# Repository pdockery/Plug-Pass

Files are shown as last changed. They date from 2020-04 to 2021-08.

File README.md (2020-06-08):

# Plug-Pass

Clatskanie People's Utility District (PUD) is a public, not-for-profit electric utility, governed by a locally-elected Board of Directors serving the Oregon communities and surrounding areas of Rainier, Westport, and Clatskanie.  The vast majority of our customers commute for work, and Clatskanie PUD designed its electric vehicle to minimize cost and maximize value for its commuting customers.  

Plug-Pass is a subscription-based, electric-vehicle public charging program developed to provide commuters easy access to low-cost charging service at their workplaces.  The first deployment of the Plug-Pass program was at a location where access to the parking spots was easily monitored, and the initial offering only used timers to control electricity.  In considering ways to expand the program to locations that aren't easily monitored, staff is developing low-cost control mechanisms to enable subscribers to initiate charging while preventing unauthorized parties from easily accessing the service.

This program is designed to be open-source in the hope that by sharing the program design broadly we may be able to expand the number of utilities employing similar techniques, and thereby lower the implementation costs for offering the program to more locations in our service territory.

Included in this repository is open-source information that has been used in our pilot program:
* Form of Electric Vehicle Public Charging Rate Design<br>
* Summary of Clatskanie PUD's Electric Vehicle Public Charging Program Design<br>
* Worksheet for calculating public charging rates (pending)<br>
* Form of Plug-Pass subscription agreement (pending)

Under development in this repository are open-source projects to be deployed and tested
* Software for arduino nano based plug-pass outlet control platform
* Control board design and configuration 
* Component list for Plug-Pass outlet

<b>For more information about Clatskanie PUD's EV charging program visit:<b>
https://clatskaniepud.com/ev

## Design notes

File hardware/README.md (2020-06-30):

# Hardware

Contains the design files for the components for the switch including 
* KiCAD files for PCB
* FreeCAD files for 3D printable housing
* Bill of materials to assemble the switch

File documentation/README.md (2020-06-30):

# Documentation

This folder includes documentation used in our pilot program including:
* Summary of Clatskanie PUD's Electric Vehicle Public Charging Program Design
* Summary of Clatskanie PUD's Electric Vehicle Public Charging Rate Design
* Plug-Pass promo video
* Form of Electric Vehicle Public Charging Rate Design
* Worksheet for calculating public charging rates (pending)
* Form of Plug-Pass subscription agreement (pending)

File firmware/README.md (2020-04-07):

# Firmware

This is the directory for arduino nano firmware development.

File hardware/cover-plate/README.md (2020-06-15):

# Cover Plate
A 3D printable cover plate for plug-pass control board

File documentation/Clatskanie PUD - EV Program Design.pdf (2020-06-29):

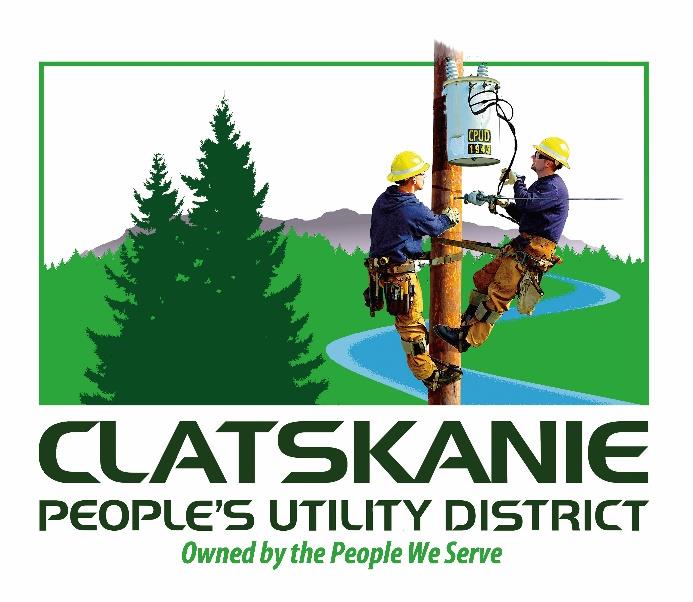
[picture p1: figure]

# Electric Vehicle Public Charging Program Overview

Paul Dockery, Power Manager June 30, 2020

# Clatskanie People’s Utility District

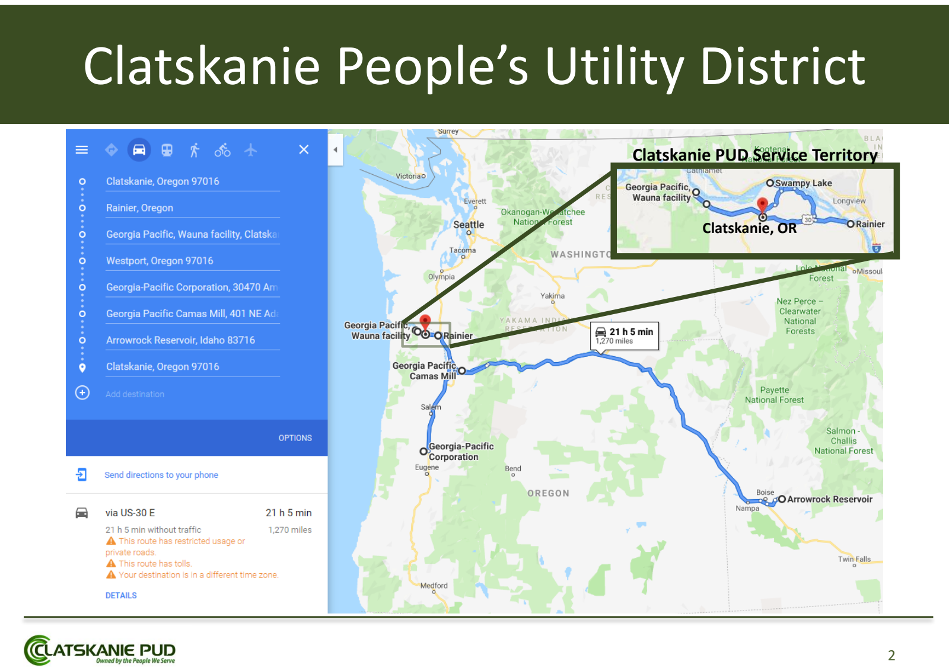
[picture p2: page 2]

Clatskanie PUD Service Territory

Clatskanie, OR

# Program Principles

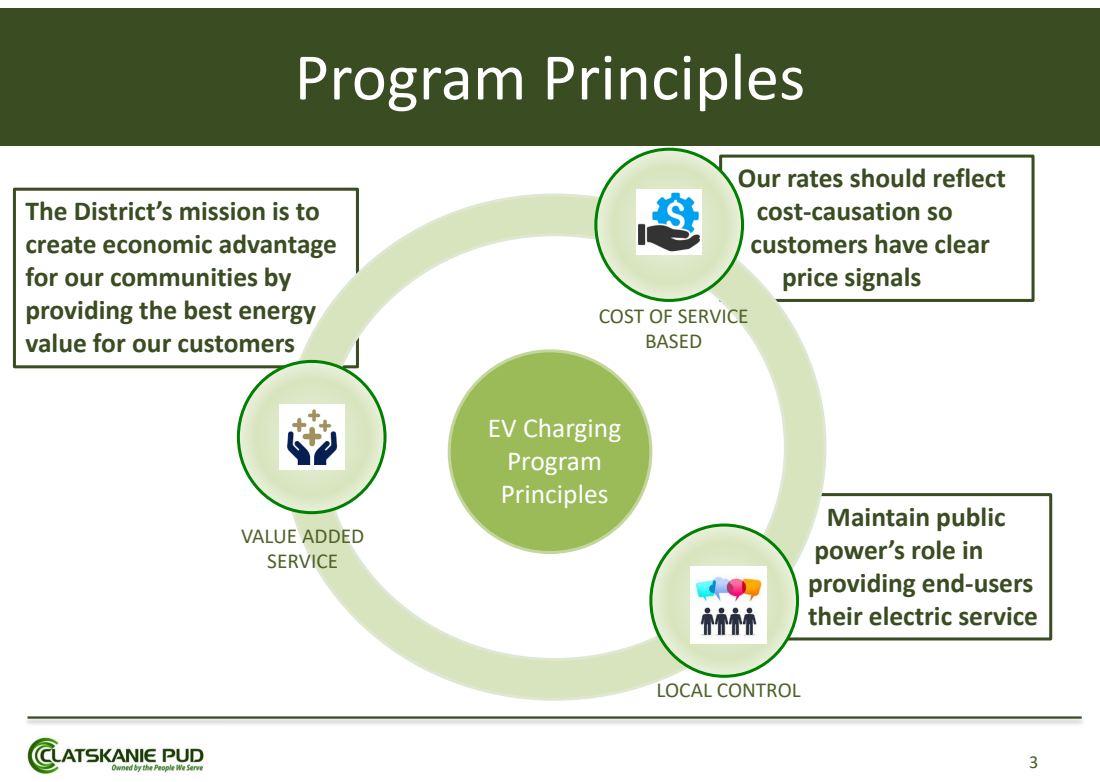
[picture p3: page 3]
EV Charging Program Principles; VALUE ADDED SERVICE; LOCAL CONTROL

Our rates should reflect
cost-causation so
customers have clear
price signals

The District’s mission is to
create economic advantage
for our communities by
providing the best energy
value for our customers

COST OF SERVICE
BASED

Maintain public
power’s role in
providing end-users
their electric service

# “Theory of the Case” for a rural utility EV Charging program

## Our (Clatskanie People’s Utility District) underlying hypotheses:

1. The most prevalent use-case for electric vehicle (“EV”) adoption in the communities we (the “District”) serve will be by commuters
✓ Commuters: Most of our customers (70%) commute for work
x Not fleets: School buses are the only large scale “public transportation” system, and the only meaningful fleet
x Not travelers: Our service territory isn’t a hub for long-haul trucking or a major thoroughfare for travelers
x Not errands: We don’t have many shopping destinations in our service territory that would lend themselves to EV motorists using public chargers during errands

### 2. In-home will be the primary location for EV charging as range continues to

improve (we don’t want to over-invest in public charging infrastructure)
3. High penetration rates of EVs in our service territory increases the District’s peak demand risk, unless charging is done in a smartTM way
4. The consumer-owned utility business model is well suited for providing low-cost electric service to EVs, including public charging services

*Source: U.S. Census Bureau, OnTheMap Application and LEHD Origin-Destination Employment Statistics

### The market we’re targeting is the ~$4.7 million of annual fuel cost paid by the more than 2,800 motorists who commute to or from our service territory to work

# “Theory of the Case” for a rural utility EV Charging program

$-

$20

$40

$60

$80

$100

$120

$140

$160

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
1,000

<10 miles
one way

10-24 miles
one way

25-50 miles
one way

>50 miles
one way

One way cost per commuter per month

# of commuters*

Commuters Living in District

# of Commuters | Fuel Cost

$-

$20

$40

$60

$80

$100

$120

$140

$160

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
<10 miles
one way

10-24 miles
one way

25-50 miles
one way

>50 miles
one way

One way cost per commuter per month

# of Commuters*

Commuters Working in District

# of Commuters | Fuel Cost

# Business Plan Components

## In-Home Charging

## Treat it like any other appliance - In-home charging should be the most cost-effective way for motorists who live in our service territory to re-charge their vehicle - Our residential rate structure is indifferent to end-use, and greater penetration of EVs improves our financial metrics

## Public Charging

## Reduce barriers to adoption and provide competitive services - Own EV public charging equipment - Set rates for end-users of our (owned) public charging equipment that sends price signals which reflect equipment and system costs

# Public Charging Services

## Unmetered outlet

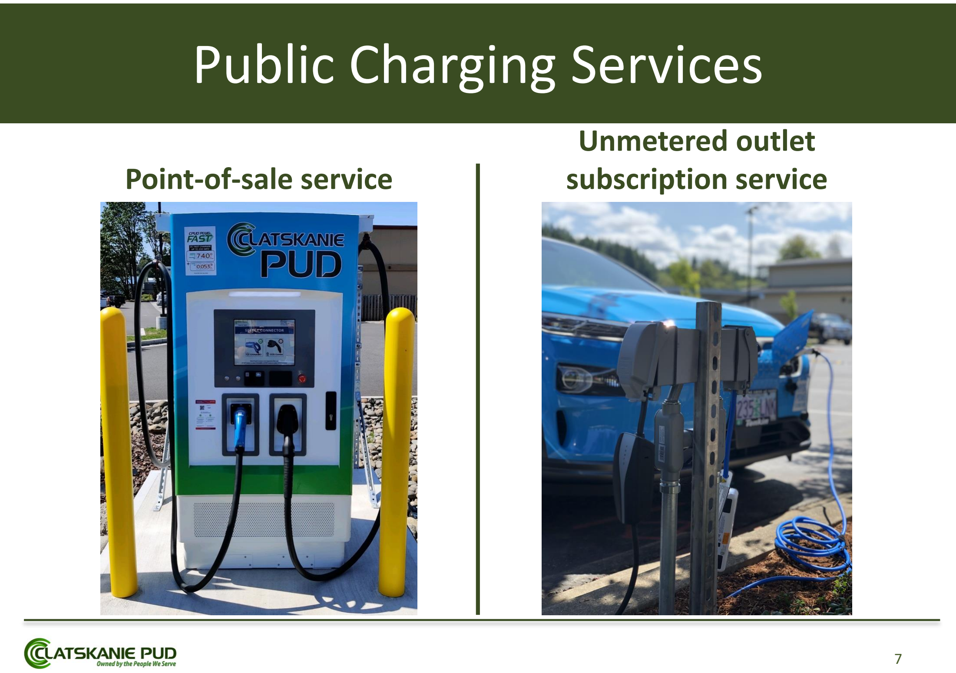
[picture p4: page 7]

## Point-of-sale service

## subscription service

# Unmetered Outlet Subscription Service

### - 120V or 240V outlet installed at commuter parking spots for a fixed monthly fee (we’re branding it “CPUD Plug Pass”)

– The employer provides the parking spot
– The District installs the line extension and outlet (at District expense)
– The District bills the subscribers a fixed monthly fee
– Subscribers provide their own charging cable and pay a fixed monthly fee

- Commuters can top off with their own charging cord using a least-cost-service without having to move their vehicle during the day - Employers don’t have to subsidize EV charging for their employees - The District increases its customer base and energy sales; billing for the subscriptions are processed using our existing software just like any other customer bill, even if they don’t live in the service territory

# Use Cases and Public Charging Services

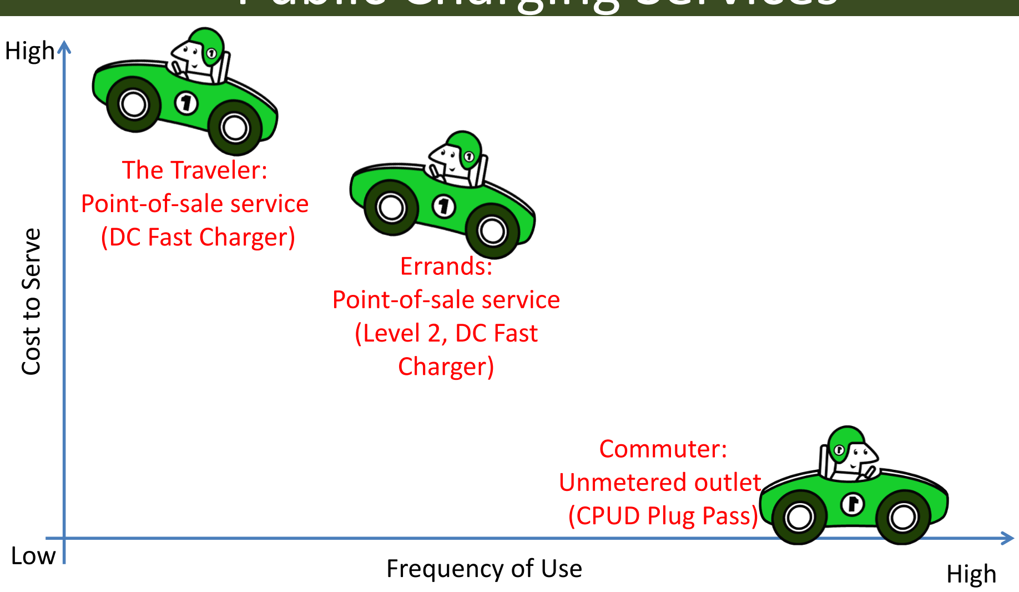
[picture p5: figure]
High; Low; High Cost to Serve; Commuter: Unmetered outlet (CPUD Plug Pass); The Traveler: Point-of-sale service (DC Fast Charger); Errands: Point-of-sale service (Level 2, DC Fast Charger); Frequency of Use

# Public Charging Service Infographic:

# Communicating price signals

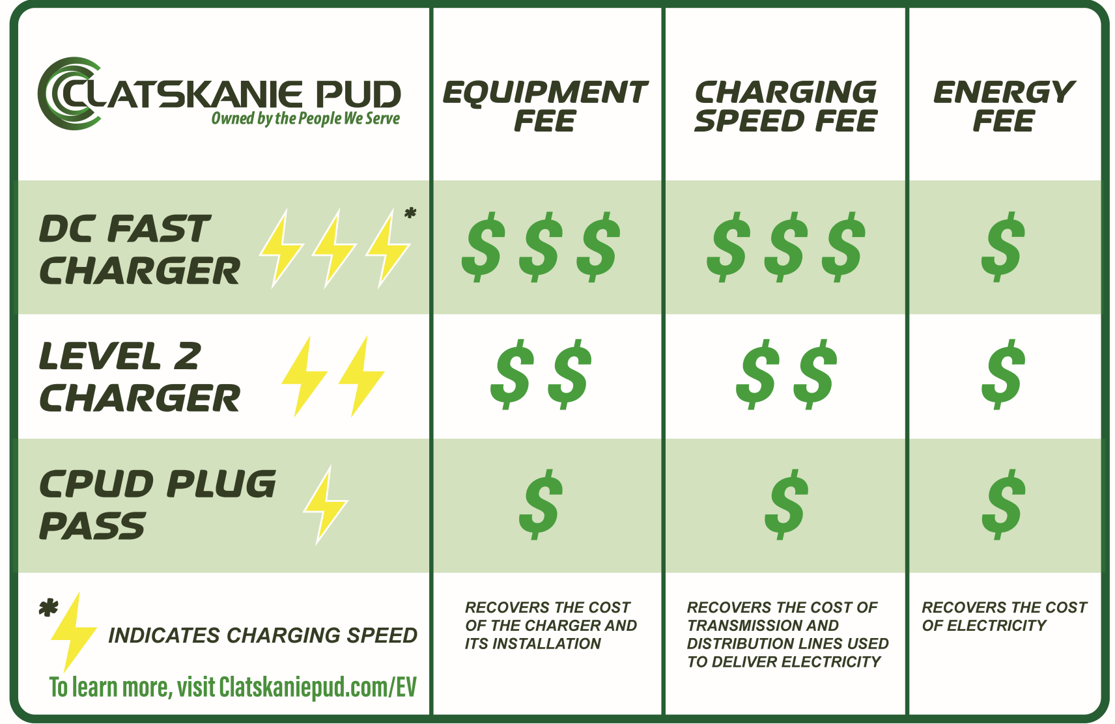
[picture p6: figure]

# Public Charging Rates

# Unmetered Outlet Subscription Service

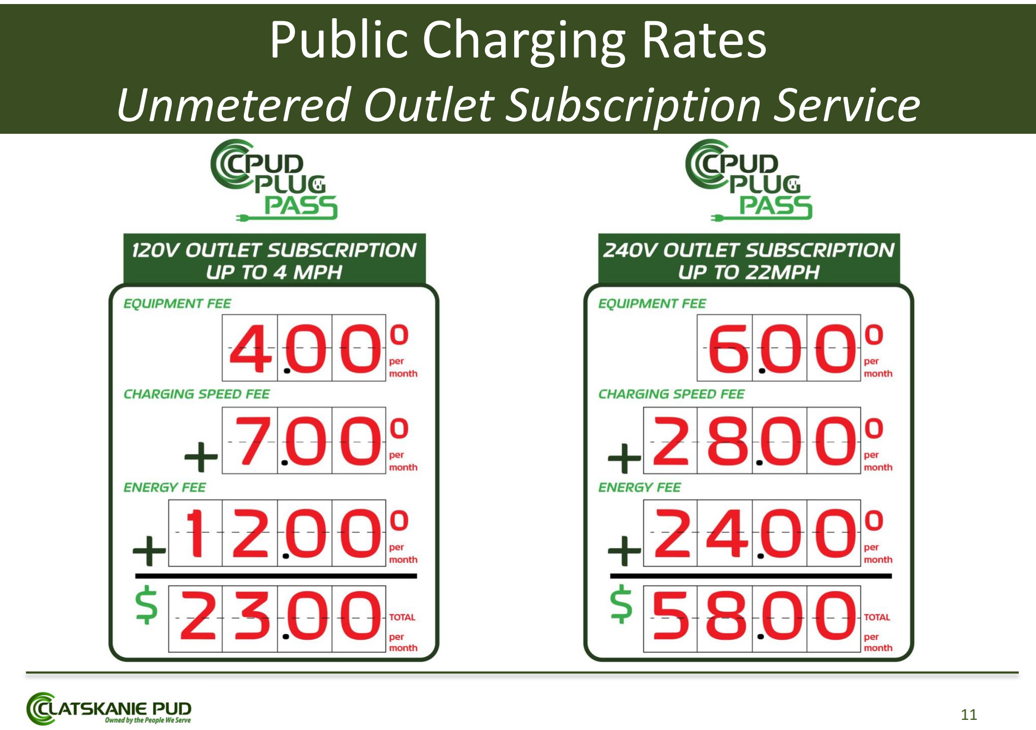
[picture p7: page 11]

*Source: U.S. Census Bureau, OnTheMap Application and LEHD Origin-Destination Employment Statistics

# Value Proposition

$-

$20

$40

$60

$80

$100

$120

$140

$160

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
<10 miles
one way

10-24 miles
one way

25-50 miles
one way

>50 miles
one way

One way cost per commuter per month

# of Commuters*

Commuters Working in District

# of Commuters | Fuel Cost | PUD Subscription/Month

The District increases energy sales and mitigates peak demand risk. Commuters save on fuel cost; the average commuter in our service territory drives 28 miles one-way and would save ~$1,355/year in fuel costs (88% savings on fuel) with an electric vehicle.

$-

$20

$40

$60

$80

$100

$120

$140

$160

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
1,000

<10 miles
one way

10-24 miles
one way

25-50 miles
one way

>50 miles
one way

One way cost per commuter per month

# of commuters*

Commuters Living in District

# of Commuters | Fuel Cost | Electric Cost/Month

# Comparing Commuter Strategies costs incurred by an average commuter

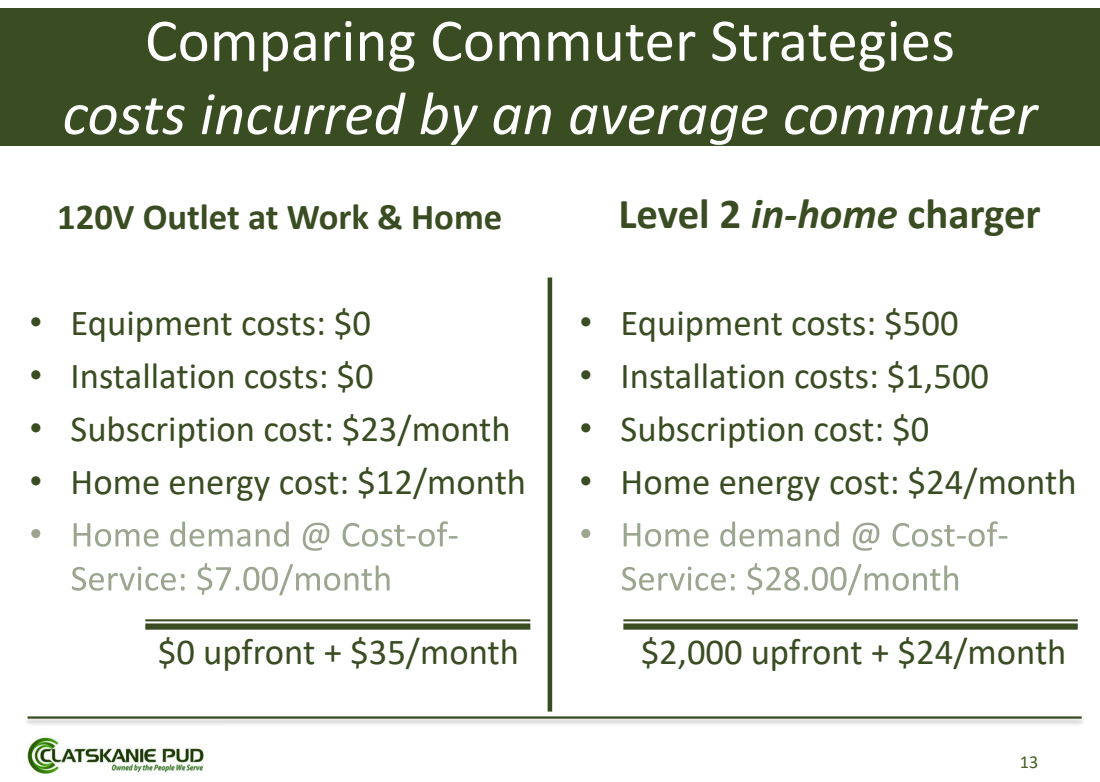
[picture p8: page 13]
$0 upfront + $35/month; $2,000 upfront + $24/month

Level 2 in-home charger

120V Outlet at Work & Home

• Equipment costs: $0
• Installation costs: $0
• Subscription cost: $23/month
• Home energy cost: $12/month

• Equipment costs: $500
• Installation costs: $1,500
• Subscription cost: $0
• Home energy cost: $24/month

# Public Charging Rates

# Point-of-Sale Service

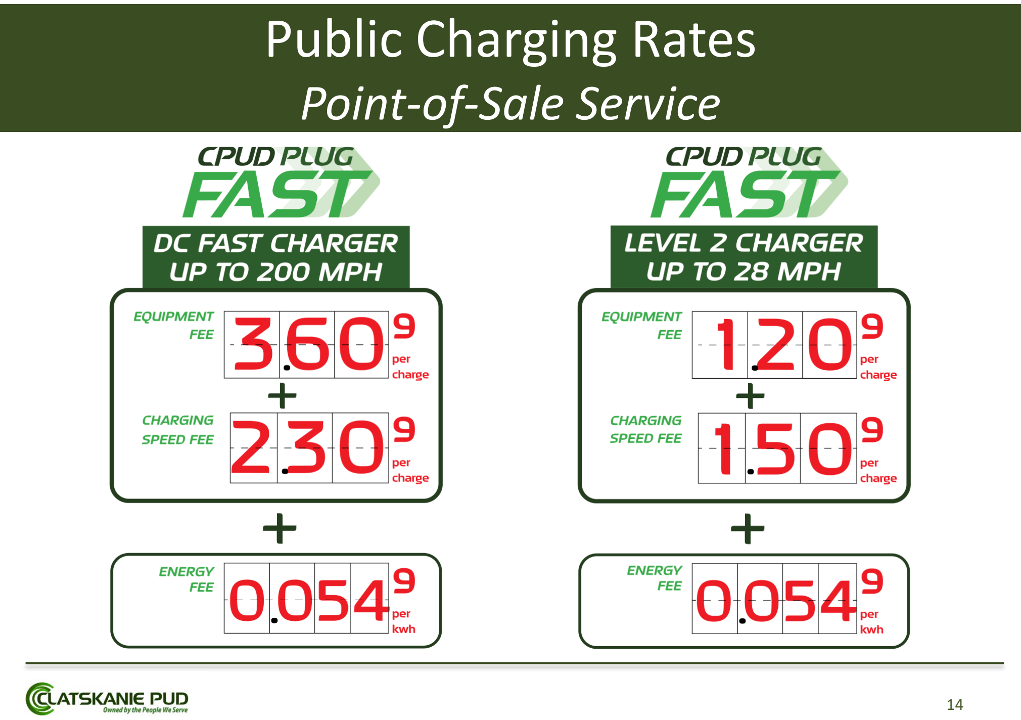
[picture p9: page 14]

# Comparing Workplace EV Public Charging Service Strategies

## Level 2 Charging

## - Costs commuter ~$78/month² - Costs District an estimated $3.3 million¹ to offer program

– 8.1% return on investment

## - Charging is subject to availability - Employees need to coordinate swapping vehicles

## 240V Outlet Charging

## - Costs commuter $58/month - Costs District an estimated $515k¹ to offer program

– 16.7% return on investment

## - Commuter has a reserved parking spot with outlet - Commuter doesn’t need to move car during the day

1
: includes line extensions, DC fast chargers, level 2 chargers, outlets, maintenance, administrative and promotional costs over 25 year program period
: based on same energy consumption as embedded in 240V subscription

# Four arguments for outlets

1. An outlet meets the needs of most commuters
– EVs charge at ~4 miles per hour on a 20 amp, 120V outlet; a commuter plugged into an outlet while parked at home and work for 16 total hours per day would capture ~64 miles worth of energy
– The average daily commute in our (rural) service territory is ~56 miles
2. Level 2 chargers are payment kiosks with an extension cord
– Installing an unmetered outlet instead of a level 2 charger removes the cost of the payment kiosk and extension cord; and simple, low-cost ways to restrict access can be priced into subscriptions
3. Outlets are technology indifferent and less expensive to install
– The low-upfront cost mitigates the risk of slower-than-expect adoption curves
4. Increasing the load-factor of EV charging by spreading charging over more hours at a lower speed makes more efficient use of our distribution system
– PNUCC’s June 2019 report on Electrification¹ highlights that increased workplace charging may have a beneficial impact on evening peaks as well
1. Report titled A Discussion on Electrifying Light Duty Vehicles and Natural Gas Heating in the Northwest https://www.pnucc.org/sites/default/files/PNUCC_NWGA%20Electrification%20Paper_1.pdf

# Closing Thoughts

- Public power utilities can add value through the design of the products and services we offer that others can’t or won’t - Calculating EV public charging fees for end-use-motorists can be simple, the hard part is educating customers on cost-causation - A Charging Speed Fee normalizes charging for peak demand to recover use of transmission and distribution system, and enhances future implementation of Demand Response solutions

- Innovative expansion of low-cost, outlet-based,

## subscription charging increases access to electric vehicles for low-income groups and increases the feasibility of equitable adoption of Zero Emission Vehicles

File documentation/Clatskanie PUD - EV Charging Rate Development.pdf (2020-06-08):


# Electric Vehicle Public Charging Rates

Paul Dockery, Power Manager

# Clatskanie People’s Utility District

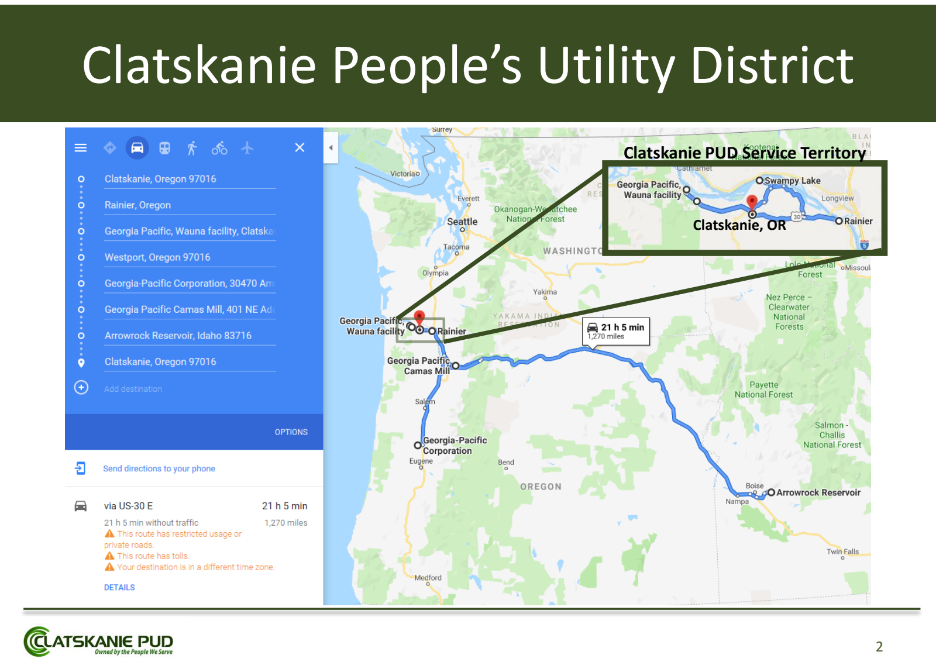
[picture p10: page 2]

Clatskanie PUD Service Territory

Clatskanie, OR

# Program Principles

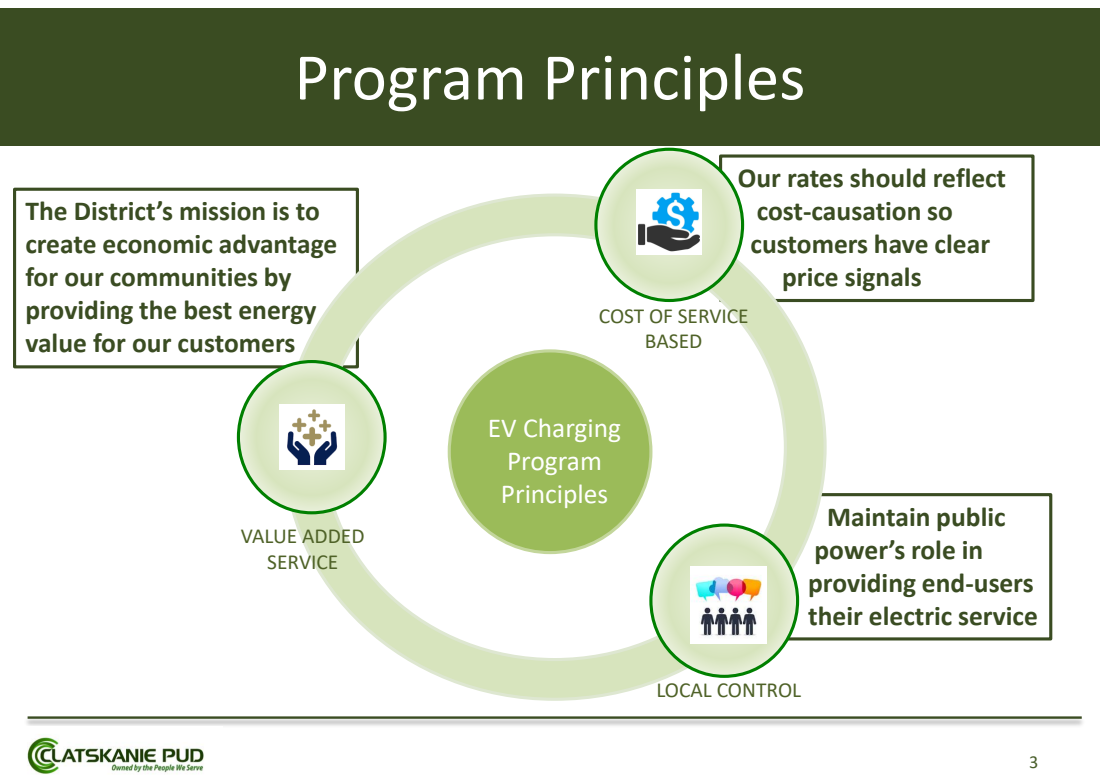
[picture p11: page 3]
EV Charging Program Principles; VALUE ADDED SERVICE; LOCAL CONTROL

Our rates should reflect
cost-causation so
customers have clear
price signals

The District’s mission is to
create economic advantage
for our communities by
providing the best energy
value for our customers

COST OF SERVICE
BASED

Maintain public
power’s role in
providing end-users
their electric service

# “Theory of the Case” for a rural utility EV Charging program

## Our (Clatskanie People’s Utility District) underlying hypotheses:

1. The most prevalent use-case for electric vehicle (“EV”) adoption in the communities we (the “District”) serve will be by commuters
✓ Commuters: Most of our customers (70%) commute for work
x Not fleets: School buses are the only large scale “public transportation” system, and the only meaningful fleet
x Not travelers: Our service territory isn’t a hub for long-haul trucking or a major thoroughfare for travelers
x Not errands: We don’t have many shopping destinations in our service territory that would lend themselves to EV motorists using public chargers during errands

### 2. In-home will be the primary location for EV charging as range continues to

improve (we don’t want to over-invest in public charging infrastructure)
3. High penetration rates of EVs in our service territory increases the District’s peak demand risk, unless charging is done in a smartTM way
4. The consumer-owned utility business model is well suited for providing low-cost electric service to EVs, including public charging services

# Business Plan Components

## In-Home Charging

## Treat it like any other appliance - In-home charging should be the most cost-effective way for motorists who live in our service territory to re-charge their vehicle - Our residential rate structure is indifferent to end-use, and greater penetration of EVs improves our financial metrics

## Public Charging

## Reduce barriers to adoption and provide competitive services - Own EV public charging equipment - Set rates for end-users of our (owned) public charging equipment that sends price signals which reflect equipment and system costs

# Our Program Offerings: EV Public Charging Services

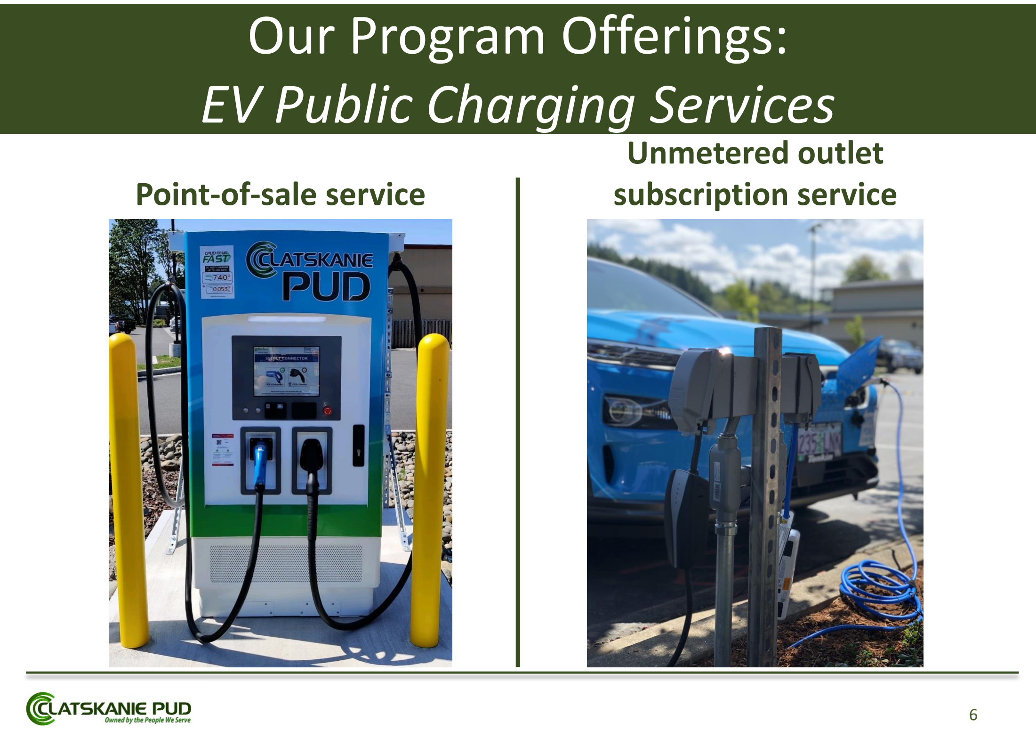
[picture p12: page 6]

## Point-of-sale service

## Unmetered outlet subscription service

# Public Charging Service Infographic:

# Communicating the price of speed


# Public Charging Rates

# Unmetered Outlet Subscription Service

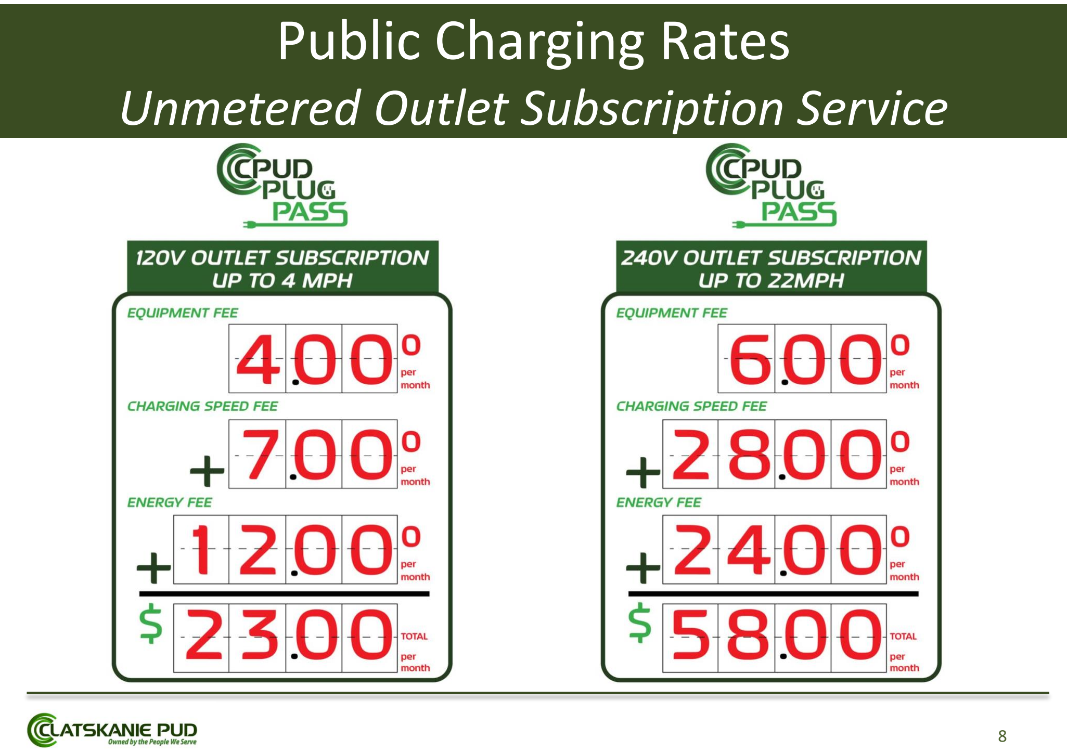
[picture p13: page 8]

# Unmetered Outlet Subscription Service: 120V Outlet Rate Calculation

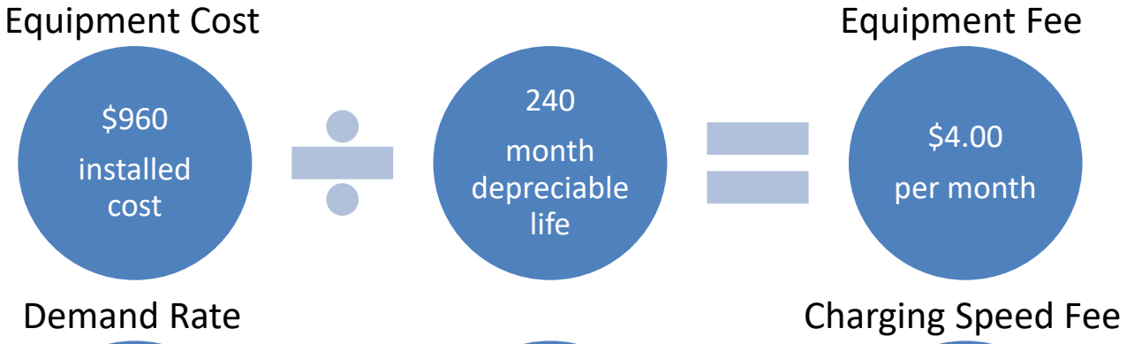
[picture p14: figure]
installed cost; month depreciable life; per month; Equipment Cost; Equipment Fee; Demand Rate; Charging Speed Fee
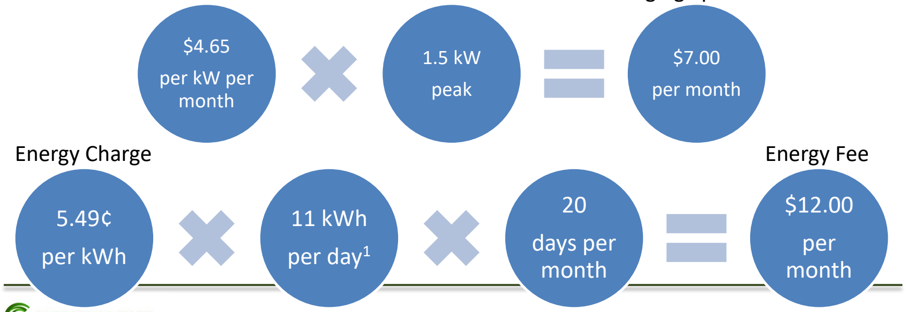
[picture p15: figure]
per kW per month; peak; per month; per kWh; 11 kWh per day¹; days per month; Energy Charge; Energy Fee

: Based on average one-way commute to work for our service territory as published by U.S. Census Bureau, OnTheMap Application and LEHD Origin-Destination Employment Statistics

# Comparing Commuter Strategies costs incurred by an average commuter

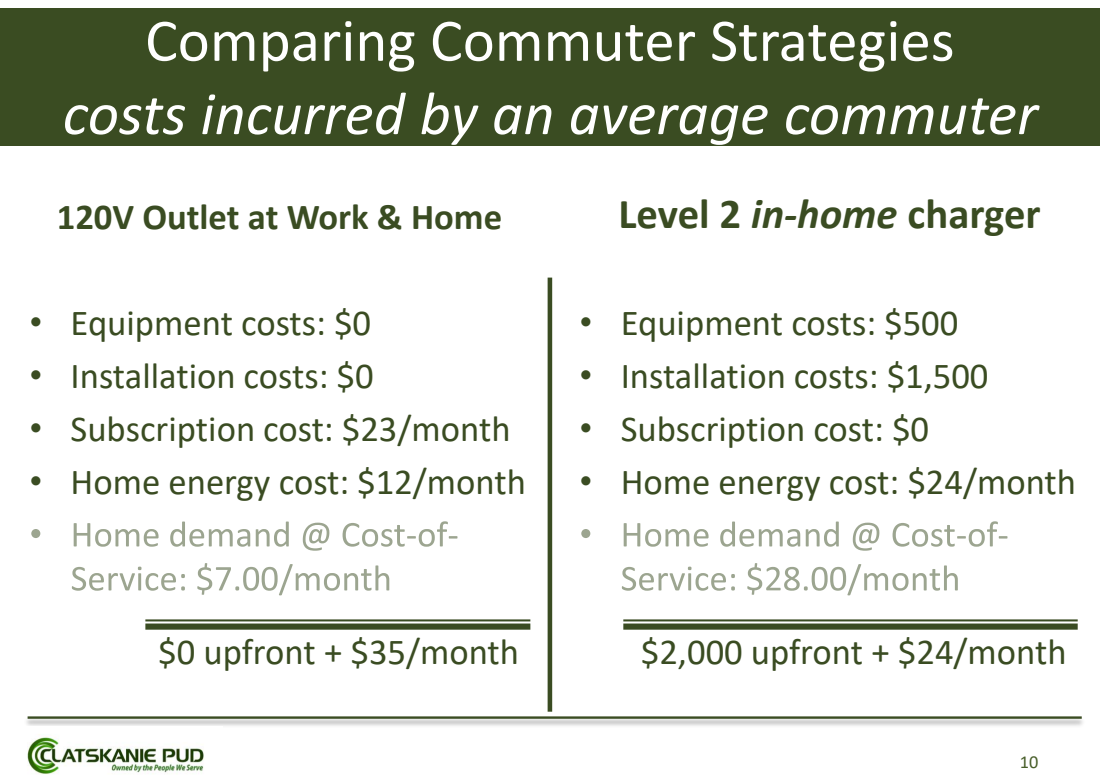
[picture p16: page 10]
$0 upfront + $35/month; $2,000 upfront + $24/month

Level 2 in-home charger

120V Outlet at Work & Home

• Equipment costs: $0
• Installation costs: $0
• Subscription cost: $23/month
• Home energy cost: $12/month

• Equipment costs: $500
• Installation costs: $1,500
• Subscription cost: $0
• Home energy cost: $24/month

# Public Charging Rates

# Point-of-Sale Service

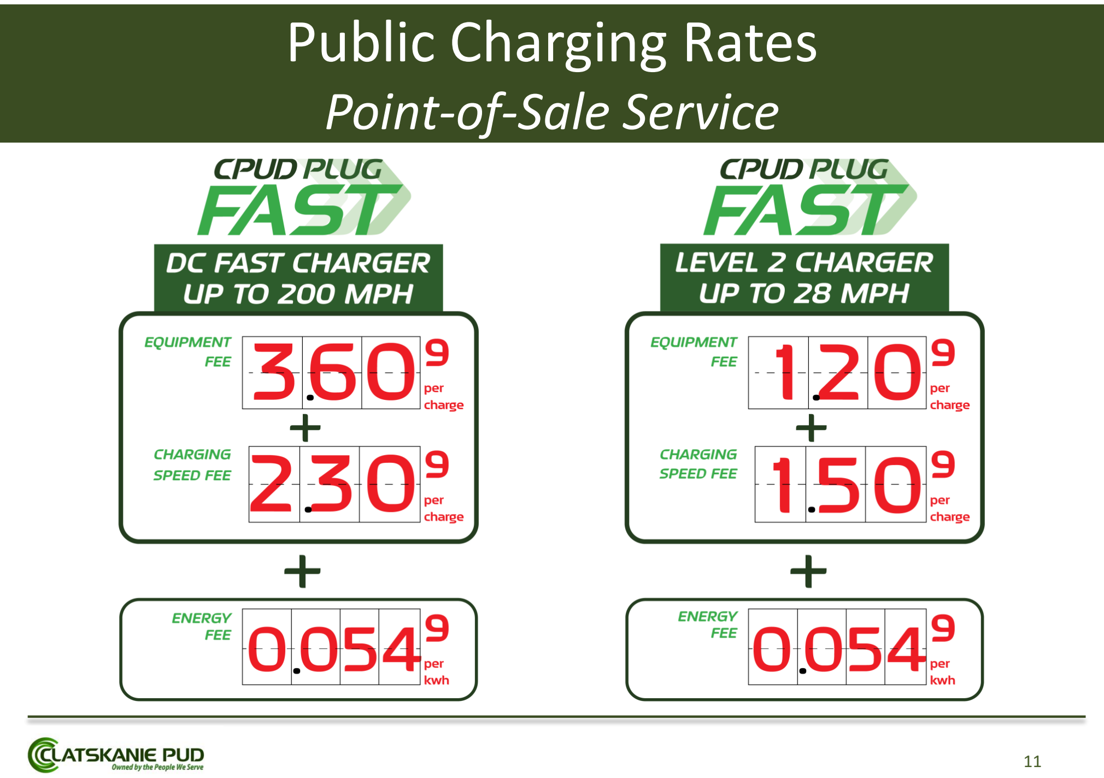
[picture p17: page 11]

# Point-of-Sale Service: DC Fast Charger Rate Calculation

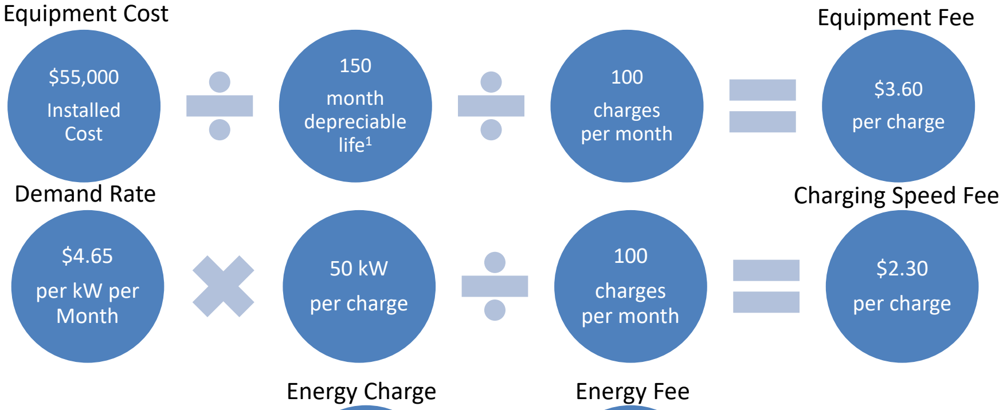
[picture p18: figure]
Installed Cost; month depreciable life¹; charges per month; per charge; Equipment Cost; Equipment Fee; per kW per Month; Demand Rate; Charging Speed Fee; Energy Charge; Energy Fee
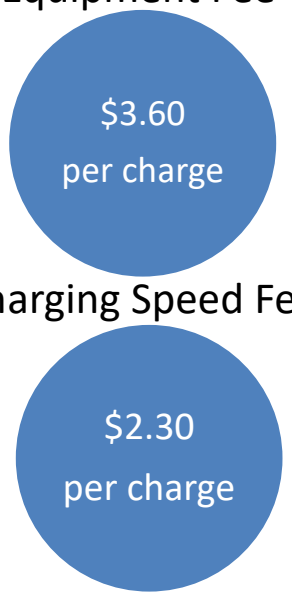
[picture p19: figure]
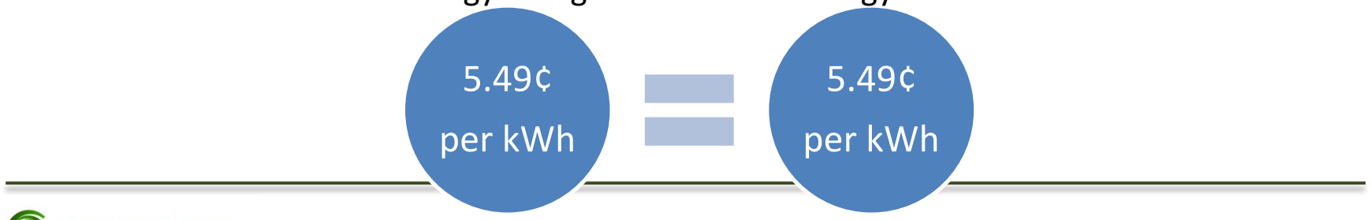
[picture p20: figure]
per kWh

: DC fast charger depreciated over a 10 year period and line extensions depreciated over 20 years

# Point-of-Sale Service: Level 2 Charger Rate Calculation

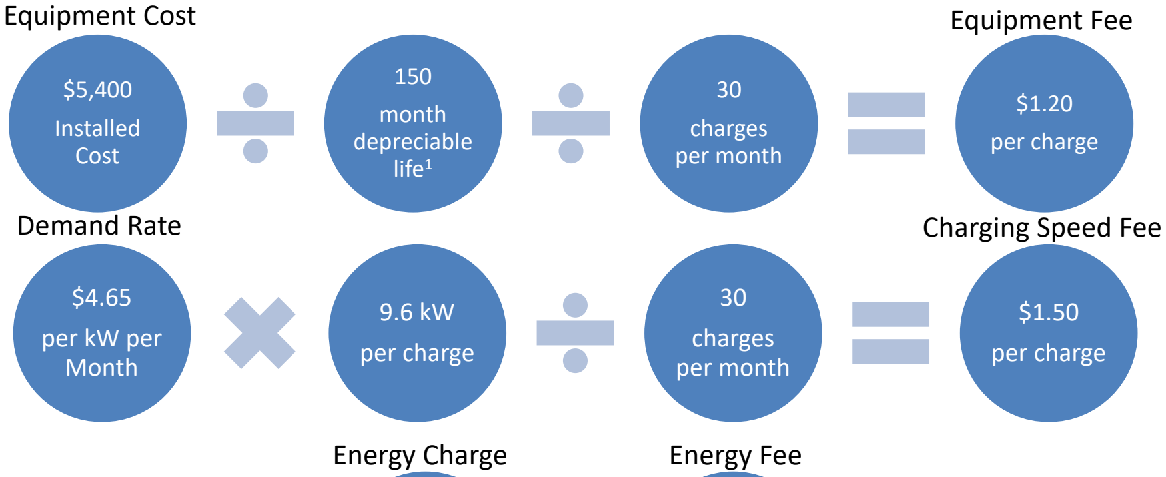
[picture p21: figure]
Installed Cost; month depreciable life¹; charges per month; per charge; Equipment Cost; Equipment Fee; per kW per Month; Demand Rate; Charging Speed Fee; Energy Charge; Energy Fee
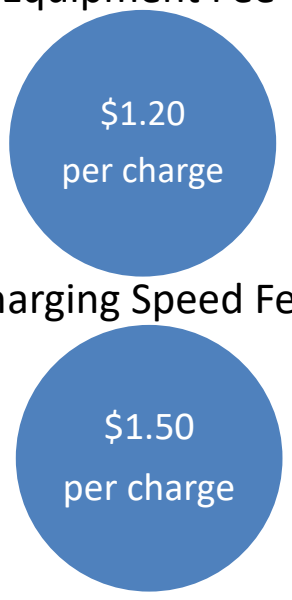
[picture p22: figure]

: Level 2 charger depreciated over a 10 year period and line extensions depreciated over 20 years

# Comparing Workplace EV Public Charging Service Strategies

## Level 2 Charging

## - Costs commuter ~$78/month² - Costs District an estimated $3.3 million¹ to offer program

– 8.1% return on investment

## - Charging is subject to availability - Employees need to coordinate swapping vehicles

## 240V Outlet Charging

## - Costs commuter $58/month - Costs District an estimated $515k¹ to offer program

– 16.7% return on investment

## - Commuter has a reserved parking spot with outlet - Commuter doesn’t need to move car during the day

1
: includes line extensions, DC fast chargers, level 2 chargers, outlets, maintenance, administrative and promotional costs over 25 year program period
: based on same energy consumption as embedded in 240V subscription

# Four arguments for outlets

1. An outlet meets the needs of most commuters
– EVs charge at ~4 miles per hour on a 20 amp, 120V outlet; a commuter plugged into an outlet while parked at home and work for 16 total hours per day would capture ~64 miles worth of energy
– The average daily commute in our (rural) service territory is ~56 miles
2. Level 2 chargers are payment kiosks with an extension cord
– Installing an unmetered outlet instead of a level 2 charger removes the cost of the payment kiosk and extension cord; and simple, low-cost ways to restrict access can be priced into subscriptions
3. Outlets are technology indifferent and less expensive to install
– The low-upfront cost mitigates the risk of slower-than-expect adoption curves
4. Increasing the load-factor of EV charging by spreading charging over more hours at a lower speed makes more efficient use of our distribution system
– PNUCC’s June 2019 report on Electrification¹ highlights that increased workplace charging may have a beneficial impact on evening peaks as well
1. Report titled A Discussion on Electrifying Light Duty Vehicles and Natural Gas Heating in the Northwest https://www.pnucc.org/sites/default/files/PNUCC_NWGA%20Electrification%20Paper_1.pdf

# Competitive Scan: EV Rate Design

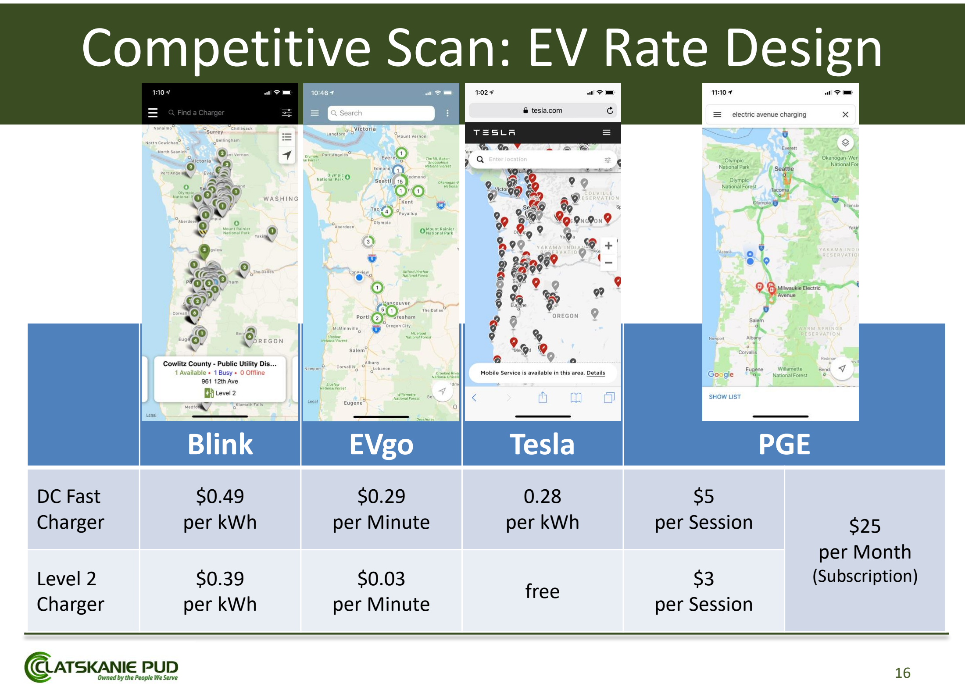
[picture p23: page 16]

| Blink | EVgo | Tesla | PGE
DC Fast Charger | $0.49 per kWh | $0.29 per Minute | 0.28 per kWh | $5 per Session | $25 per Month (Subscription)
Level 2 Charger | $0.39 per kWh | per Minute $0.03 | free | $3 per Session

# Competitive Scan: Public Charging Services

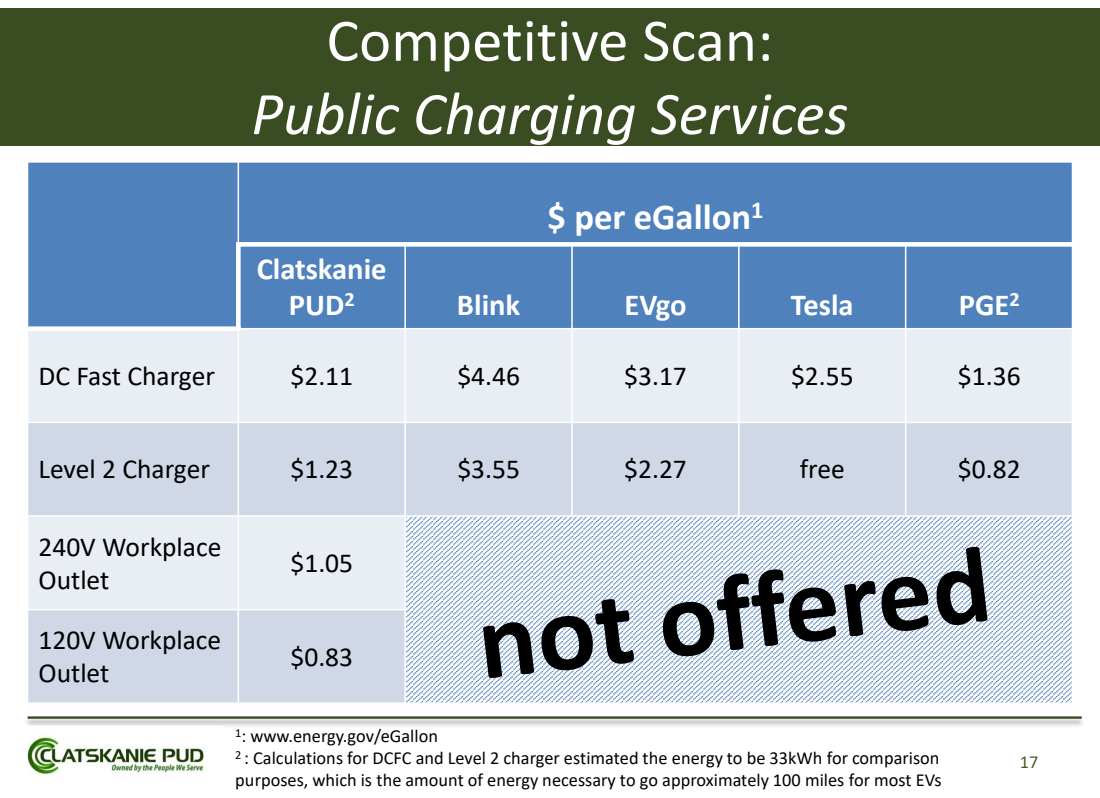
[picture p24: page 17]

$ per eGallon¹

Clatskanie PUD² | Blink | EVgo | Tesla | PGE²

DC Fast Charger | $2.11 | $4.46 | $3.17 | $2.55 | $1.36

Level 2 Charger | $1.23 | $3.55 | $2.27 | free | $0.82

240V Workplace Outlet | $1.05

120V Workplace Outlet | $0.83

: www.energy.gov/eGallon
2 : Calculations for DCFC and Level 2 charger estimated the energy to be 33kWh for comparison
purposes, which is the amount of energy necessary to go approximately 100 miles for most EVs

# Closing Thoughts

- Public power utilities can add value through the design of the products and services we offer that others can’t or won’t - Calculating EV public charging fees for end-use-motorists can be simple, the hard part is educating customers on cost-causation - A Charging Speed Fee may be a good way to normalize the idea of charging for peak demand to recover use of transmission and distribution system - The terms of service for an EV public charging service rate schedule are different than traditional offerings

# Other Resources

# We’re open source!

# All our resources (including this presentation) are available, and updated on GitHub: https://github.com/pdockery/Plug-Pass

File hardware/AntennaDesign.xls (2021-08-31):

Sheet: Antenna Topology I and II
 | Antenna Matching Calculations
Step 1 |  | value | unit | annotation
 | f = | 13560000 | [Hz]
 | omega = | 85199992.77 | [s-1] |  |  |  | calculated
 |  |  |  |  |  |  | to be filled in
 | L0 = | 5.6e-07 | [H]
 | fr0 = | 14400000 | [Hz]
 | C0 calculated = | 2.181359533e-10 | [F]
 | C0 = | 2.2e-10 | [F] | chosen value for C0 | fres = | 14338865.06
 | Rmatch = | 50 | [Ω]
 | Rtr = | 216.6795188
 | Xtr = | -57.8316663
Step 2 | 1st Iteration: Measurement of Antenna parameter La, Rs, Rp,fra
 | Antenna: | linear view | unit | annotation
 | La = | 3.3e-06 | [H]
 | Rs = | 1.2 | [Ω]
 | Rp = | 10900 | [Ω] | at self resonance frequency
 | fra = | 40200000 | [Hz] | self resonance frequency of the antenna
 | Rp (13.56MHz) = | 18767.64067 | [Ω] | Skin effect included
 | Ra = | 5.412 | [Ω]
 | Ca = | 4.749787905e-12 | [F]
 | Qa = | 51.950
 | RQ = | 1.980 | [Ω] | Resistance for a Qa-value of 30
Step 3 | choose an appropriate value for RQ and perform a 2nd antenna measurement for La, Rs, Rp,fra
Step 4 | 2nd Iteration: Measurement of Antenna parameter La, Rs, Rp,fra
 | Antenna: | linear view | unit | annotation
 | La = | 3.3e-06 | [H]
 | Rs = | 1.5 | [Ω]
 | Rp = | 10900 | [Ω] | at self resonance frequency
 | fra = | 40200000 | [Hz] | self resonance frequency of the antenna
 | Rp (13.56MHz) = | 18767.64067 |  | Skin effect included
 | Ra = | 5.712 | [Ω]
 | Ca = | 4.749787905e-12 | [F]
 | Qa = | 49.222
Step 5
 | Antenna: | linear view | unit | annotation
 | Lpa = | 3.3e-06 | [H]
 | Cpa = | 4.749787905e-12 | [F]
 | Rpa = | 13839.23852 | [Ω]
 | Qpa = | 49.222
Step 6 | Calculate Matching Components
 | Matching Circuit: | value | unit | annotation
 | C1 = | 1.402416576e-11 | [F]
 | C2 = | 6.043509275e-11 | [F]
Step 7 | if antenna topology II will be applied please continue with the worksheet "C1 split calculation for AT II"

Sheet: C1 split calculation for AT II
C1 Split Calculations |  |  |  |  | without detuning | with detuning
C1 | 2.12721928e-11 | 21.27 |  |  | 1 | 2
 | Before Split |  | After Split
UEMC without detuning | 5.10 | [V] | 9.50 | [V]
UEMC with detuning | 10.80 | [V] | 6.80 | [V]
UANT without detuning | 24.14 | [V] | 24.14 | [V]
UANT with detuning | 5.00 | [V] | 14.50 | [V]
Average Voltage | 9.469082 | [V]
Percentage seperation of C1: | 22.95 | %
C1S: | 92.70 | [pF]
C2S: | 27.61 | [pF]

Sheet: Antenna Topology III
 | Antenna Matching Calculations
 | The two columns are identical. The left column shows values in scientific units and the right column shows values in a more common format. The columns are independent.
 | The following calculations are only for half of the antenna matching. Rmatch is therefore 35 Ohm instead of 70 Ohm. But the measurement of the antenna itself has to be done for the whole antenna. Equivalent cirquit is for the total antenna!
Step 1 |  | value | unit | easy values | easy unit | annotation | color explanation
 | f = | 13560000 | [Hz] | 13.56 | [MHz] |  |  | to be filled in
 | omega = | 85199992.77 | [s-1] | 85199992.77 | [s-1] |  |  | fixed/calculated values
 | L0 = | 3.3e-07 | [H] | 0.33 | [uH]
 | Rmatch = | 35 | [Ω] | 35 | [Ω]
Step 2 | 1st Iteration: Measurement of Antenna parameter La, Rs, Rp,fra
 | Antenna: | linear view | unit |  |  | annotation
 | La = | 3.2e-06 | [H] | 3.3 | [uH]
 | Rs = | 1.1 | [Ω] | 1.11 | [Ω]
 | Rp = | 80000 | [Ω] | 80 | [kΩ] | at self resonance frequency
 | fra = | 28420000 | [Hz] | 28.4 | [MHz] | self resonance frequency of the antenna
 | Rp (13.56MHz) = | 115816.9647 | [Ω] | 115.776 | [kΩ] | Skin effect included
 | Ra = | 1.742 | [Ω] | 1.793 | [Ω]
 | Ca = | 9.800362453e-12 | [F] | 9.517 | [pF]
 | Qa = | 156.527 |  | 156.828
 | RQ = | 3.673 | [Ω] | 3.790 | [Ω] | Resistance for a Qa-value of 30
Step 3 | choose an appropriate value for RQ and perform a 2nd antenna measurement for La, Rs, Rp,fra
Step 4 | 2nd Iteration: Measurement of Antenna parameter La, Rs, Rp,fra
 | Antenna: | linear view | unit |  |  | annotation
 | La = | 3.3e-06 | [H] | 3.3000 | [uH]
 | Rs = | 7.5 | [Ω] | 7.50 | [Ω]
 | Rp = | 80000 | [Ω] | 80.00 | [kΩ] | at self resonance frequency |  |  | 2514000
 | fra = | 28000000 | [Hz] | 28.0000 | [MHz] | self resonance frequency of the antenna
 | Rp (13.56MHz) = | 114957.989 |  | 114.9580 | [kΩ] | Skin effect included
 | Ra = | 8.188 | [Ω] | 8.1877 | [Ω]
 | Ca = | 9.790621487e-12 | [F] | 9.7906 | [pF]
 | Qa = | 34.340 |  | 34.3395
Step 5
 | Antenna: | linear view | unit |  |  | annotation
 | Lpa = | 3.3e-06 | [H] | 3.3000 | [uH]
 | Cpa = | 9.790621487e-12 | [F] | 9.7906 | [pF]
 | Rpa = | 9654.898073 | [Ω] | 9.6549 | [kΩ]
 | Qpa = | 34.340 |  | 34.340
 | Given Parameters:
 | L0 | 3.3e-07
 | ω | 85199992.77 |  |  | Rmatch | 35
 | Equivalent circuit of the total antenna:
 | Antenna | value | unit |  |  | annotation
 | La = | 3.3e-06 | [H] | 3.300 | [uH]
 | Ca = | 9.790621487e-12 | [F] | 9.791 | [pF]
 | Rp = | 9654.898073 | [Ω] | 9.655 | [kΩ]
 | For calculation of the tuning Capacitors only half of the antenna is needed
 | Antenna | value | unit |  |  | annotation
 | La/2 = | 1.65e-06 | [H] | 1.65 | [uH]
 | Ca*2 = | 1.958124297e-11 | [F] | 19.58 | [pF]
 | Rp/2 = | 4827.449037 | [Ω] | 4.83 | [kΩ]
 | Calculation of Antenna impedance
 | Real_ant = | 6.976664972 |  | 6.977
 | Imag_ant = | 183.387079 |  | 183.387
 | Matching circuit | value | unit |  |  | annotation
 | Calculation of the antenna tuning capacitors
 | C1_1 | 5.805336166e-11 | [F] | 58.05 | [pF]
 | C1_2 | 7.130824243e-11 | [F] | 71.31 | [pF]
 | C0_1 | -3.85222434e-10 | [F] | -385.22 | [pF]
 | C0_2 | 7.126830877e-10 | [F] | 712.68 | [pF]
 | Final tuning values: |  |  |  |  | only 1 solution for C1 and CEMC is possible
 | C1 = | 7.130824243e-11 | [F] | 71.31 | [pF]
 | C0 = | 7.126830877e-10 | [F] | 712.68 | [pF]


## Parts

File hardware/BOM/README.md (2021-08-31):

# Bill of Materials

Datasheets are attached. The datasheet for the ATMEGA328P-AUR was too large to attached. it is available at:

https://www.mouser.com/datasheet/2/268/ATmega48A_PA_88A_PA_168A_PA_328_P_DS_DS40002061B-1900559.pdf

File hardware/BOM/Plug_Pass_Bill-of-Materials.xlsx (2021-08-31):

Item # | Quantity | Reference | Value | Footprint | Description | MPN | Manufacturer | Type
1 | 1 | B1 | CR1220 | CR1220 | CR1220 COIN CELL SM RETAINER | 2894 | Keystone Electronics | SMD
2 | 5 | > C4, C5, C19, C21, C22 | 10µF | 0603-1608X90N | Multilayer Ceramic Capacitors MLCC - SMD/SMT 10UF 25V 10% 0603 | GRM188R61E106KA73D | Murata Electronics | SMD
3 | 7 | > C1-C3, C8, C17, C18, C20 | 0.1µF | 0603-1608X90N | Multilayer Ceramic Capacitors MLCC - SMD/SMT 50V .1uF X7R 0603 10% AEC-Q200 | C0603C104K5RAC3121 | KEMET | SMD
4 | 2 | > C11, C14 | 220pF | 0402-1005X55N | Multilayer Ceramic Capacitors MLCC - SMD/SMT 50V 220pF X7R 0402 10% AEC-Q200 | C0402S221K5RACAUTO | KEMET | SMD
5 | 1 | C23 | 1000pF | 0603-1608X90N | Multilayer Ceramic Capacitors MLCC - SMD/SMT 50V 1000pF X7R AUTO 5mm Flex VW80808 | C0603X102K5RAC3316 | KEMET | SMD
6 | 2 | > C24, C25 | 33pF | 0603-1608X90N | Multilayer Ceramic Capacitors MLCC - SMD/SMT 50V 33pF 0603 X8R 10% AEC-Q200 | C0603C330K5HACAUTO | KEMET | SMD
7 | 2 | > C26, C28 | 1µF | 0402-1005X55N | Multilayer Ceramic Capacitors MLCC - SMD/SMT 0402 25VDC 1uF 10% | GRM155R61E105KA12D | Murata Electronics | SMD
8 | 2 | > C27, C31 | 4,7uF_16V | CAPAE430X550N | Aluminum Electrolytic Capacitors - SMD WCAP-ASNP 4.7uF 16V 20% SMD/SMT | 865250340002 | Wurth Elektronik | SMD
9 | 3 | > C29, C30, C33 | 100nF | 0402-1005X55N | Multilayer Ceramic Capacitors MLCC - SMD/SMT .1UF 50V 5% 0402 | GRM155R61H104JE14D | Murata Electronics | SMD
10 | 1 | C32 | 1uF | 0402-1005X55N | Multilayer Ceramic Capacitors MLCC - SMD/SMT 0402 25VDC 1uF 10% | GRM155R61E105KA12D | Murata Electronics | SMD
11 | 1 | D1 | 0025_SS1P3L-M3_84A | DO220AAL | Schottky Diodes & Rectifiers 30volt 1.0amp | SS1P3L-M3/84A | Vishay Semiconductors | SMD
12 | 1 | F1 | MFFSMF050 | 0603-1608X90N | Resettable Fuses - PPTC 6volts 40amps | MF-FSMF050X-2 | Bourns | SMD
13 | 1 | IC1 | DS3231M | Package_SO:SOIC-16W_7.5x10.3mm_P1.27mm | Real Time Clock +/-5ppm, I C Real-Time Clock | DS3231M+ | Maxim Integrated | SMD
14 | 1 | IC2 | PN532 | HVQFN40-6X6 | IC RFID RDR/TRAN 13.56MZ 40HVQFN | PN5321A3HN/C106,55 | NXP USA Inc. | SMD
15 | 0 | IC3 | NA | NA | NA | NA | NA | NA
16 | 1 | IC4 | FT232RL | digikey-footprints:SSOP-28_W5.30mm | IC USB FS SERIAL UART 28-SSOP | FT232RL-REEL | FTDI, Future Technology Devices International Ltd | SMD
17 | 1 | IC5 | ATMEGA328P-AUR | digikey-footprints:TQFP-32_7x7mm | IC MCU 8BIT 32KB FLASH 32TQFP | ATMEGA328P-AUR | Microchip Technology | SMD
18 | 1 | J1 | USB_B_Micro | MOLEX_1051330001 | USB Connectors MICRO USB B RECPT VERTICAL | 1051330001 | Molex | SMD & through-hole
19 | 1 | J2 | 505568-0271 | 5055680271 | CONN HEADER SMD 2POS 1.25MM | 5055680271 | Molex | SMD
20 | 1 | L1 | Yellow | LEDC1608X80N-AK | Standard LEDs - SMD Yellow Diffused 586nm 8mcd | HSMY-C190 | Broadcom | SMD
21 | 2 | > L3, L4 | 560nH | 0805-R2013X50N | Fixed Inductors 560nH 5% | CW201212-R56J | Bourns | SMD
22 | 2 | > L2, L5 | FERRITE | 0805-R2013X50N | Ferrite Beads 0805 0.12ohm 100MHz 1.6A | BLM21SP102SN1D | Murata Electronics | SMD
23 | 1 | PS1 | IRM-03-5 | Converter_ACDC:Converter_ACDC_MeanWell_IRM-03-xx_SMD | AC/DC CONVERTER 5V 3W | IRM-03-5S | MEAN WELL USA Inc. | SMD
24 | 1 | PWR1 | Green | LEDC1608X80N-AK | Standard LEDs - SMD Green Diffused 572nm 5mcd | HSMG-C190 | Broadcom | SMD
25 | 2 | > R2, R4 | 10k | 0402-1005X55N | Thick Film Resistors - SMD 10K OHM 1% | RC0402FR-0710KL | Yageo | SMD
26 | 1 | R7 | 1.0k | 0402-1005X55N | Thick Film Resistors - SMD 1K ohm 5% 50V General Purpose | RC0402JR-131KL | Yageo | SMD
27 | 1 | R8 | 1.69k | 0402-1005X55N | Thick Film Resistors - SMD 1.69K OHM 1% | RC0402FR-071K69L | Yageo | SMD
28 | 4 | > R9-R12 | 330 | 0402-1005X55N | Thick Film Resistors - SMD 330 OHM 1% | RC0402FR-07330RL | Yageo | SMD
29 | 1 | RLY1 | T9AS1D22-5 | RLY-T9AS1D22-5 | RELAY GEN PURPOSE SPST 30A 5V | T9AS1D22-5 | TE Connectivity Potter & Brumfield Relays | through-hole
30 | 1 | RLY2 | G5V-1-DC5 | Relay_THT_G5V-1 | RELAY GEN PURPOSE SPDT 1A 5VDC | G5V-1-DC5 | Omron Electronics Inc-EMC Div | through-hole
31 | 1 | RP1 | 1k | CAY16 | Resistor Networks & Arrays 1K 5% Convex 4resistors | CAY16-102J4LF | Bourns | SMD
32 | 1 | RX1 | Red | LEDC1608X80N-AK | Standard LEDs - SMD Red Diffused 639nm 17mcd | HSMH-C190 | Broadcom | SMD
33 | 1 | SW1 | RESET | C&K_PTS820_NO_HOLES | Tactile Switches Microminiature SMT Top Actuated | PTS820J25KSMTRLFS | C&K | SMD
34 | 1 | TX1 | Green | LEDC1608X80N-AK | Standard LEDs - SMD Green Diffused 572nm 5mcd | HSMG-C190 | Broadcom | SMD
35 | 1 | Y1 | 27.12MHz | 7M27120MAAJT | Crystals 27.120MHz 30ppm -20 +70C 18pF | 7M-27.120MAAJ-T | TXC Corporation | SMD
36 | 0 | Y2 | NA | NA | NA | NA | NA | NA
37 | 2 | C35, C36 | 22pF | 0603-1608X90N | Multilayer Ceramic Capacitors MLCC - SMD/SMT 22pF 50V NPO 5% | CC0603JRNPO9BN220 | Yageo | SMD | https://www.mouser.com/ProductDetail/Yageo/CC0603JRNPO9BN220?qs=vTakOoo5QyIVMYOUTI%2F4zA%3D%3D
39 | 2 | C6, C15 | 15pF | C_0805_2012Metric | Multilayer Ceramic Capacitors MLCC - SMD/SMT 50V 15pF C0G 0805 5% | CC0805JRNPO9BN150 | Yageo | SMD | https://www.mouser.com/ProductDetail/Yageo/CC0805JRNPO9BN150?qs=vTakOoo5QyIdTjxE3H8vpA%3D%3D
40 | 2 | C10, C13 | 62pF | C_0805_2012Metric | Multilayer Ceramic Capacitors MLCC - SMD/SMT 62pF 50V NPO 5% | CC0805JRNPO9BN620 | Yageo | SMD | https://www.mouser.com/ProductDetail/Yageo/CC0805JRNPO9BN620?qs=57cj7OiSijn%2FWRr%252BD6Xa6w%3D%3D
41 | 1 | D2 | NA | SODFL2512X100N | DIODE GEN PURP 75V 150MA SOD323F | 1N4148WS | ON Semiconductor | SMD | https://www.digikey.com/en/products/detail/on-semiconductor/1N4148WS/1873805
42 | 0 | Q1 | NA | NA | NA | NA | NA | NA | https://www.mouser.com/Semiconductors/Discrete-Semiconductors/Transistors/Bipolar-Transistors-BJT/_/N-ax1sh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
43 | 1 | R13 | 4.7k | 0402-1005X55N | Thick Film Resistors - SMD 4.7 kOhms 62.5 mW 0402 5% | RC0402JR-7D4K7L | Yageo | SMD | https://www.mouser.com/ProductDetail/Yageo/RC0402JR-7D4K7L?qs=HEu%2FF%2FCqxzL%2FxemeTzhmAg%3D%3D
44 | 2 | R1, R6 | 2 | Resistor_SMD:R_0805_2012Metric | Thick Film Resistors - SMD 1/4watts 2ohms 5% | RK73B2ATTD2R0J | KOA Speer | SMD | https://www.mouser.com/ProductDetail/KOA-Speer/RK73B2ATTD2R0J?qs=rx%252BqewZzWUdjzAQpUO86bw%3D%3D
45 | 1 | J3 | 1x8 | PinSocket_1x08_P2.54mm_Vertical_SMD_Pin1Right | CONN HDR 8POS 0.1 TIN SMD | NPTC081KFXC-RC |  | SMD | https://www.digikey.com/en/products/detail/sullins-connector-solutions/NPTC081KFXC-RC/776058

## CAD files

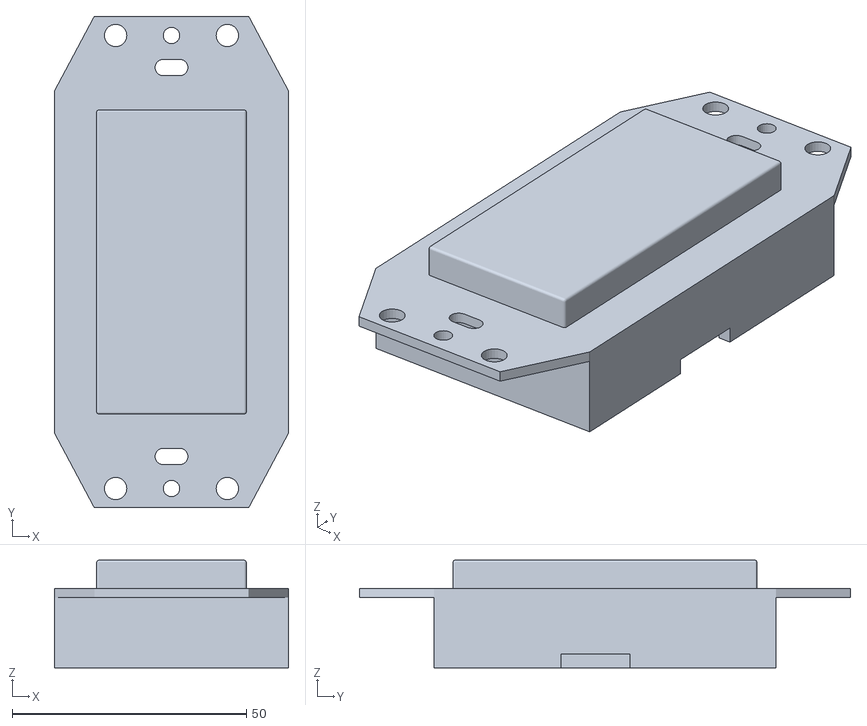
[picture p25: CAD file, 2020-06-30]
hardware/cover-plate/Plug-Pass-cover.stl
50.0 x 105.0 x 23.0

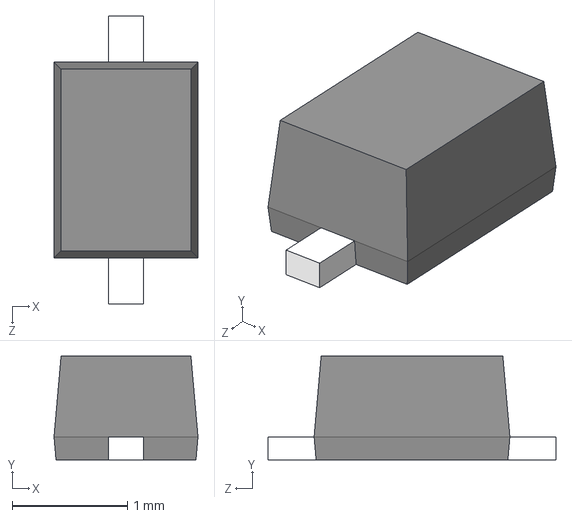
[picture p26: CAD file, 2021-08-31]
hardware/PCB/Update3-2/1N4148WS/1N4148WS.step
1.25 x 0.9 x 2.50 mm

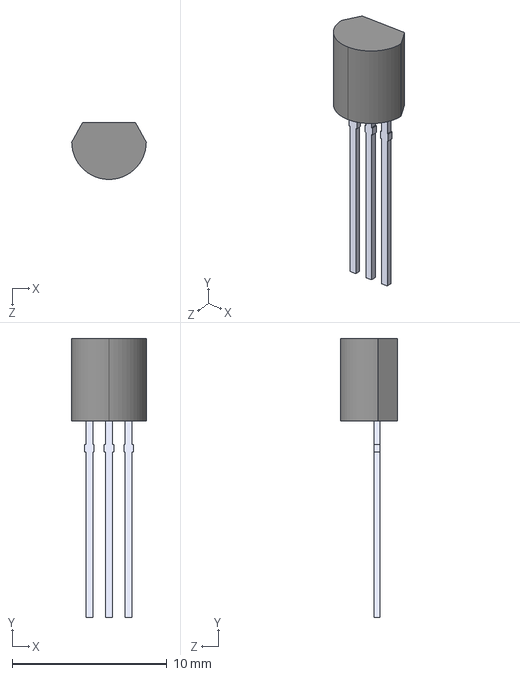
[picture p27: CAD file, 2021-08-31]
hardware/PCB/Update3-2/2N3904/2N3904.step
4.83 x 18.0 x 3.68 mm

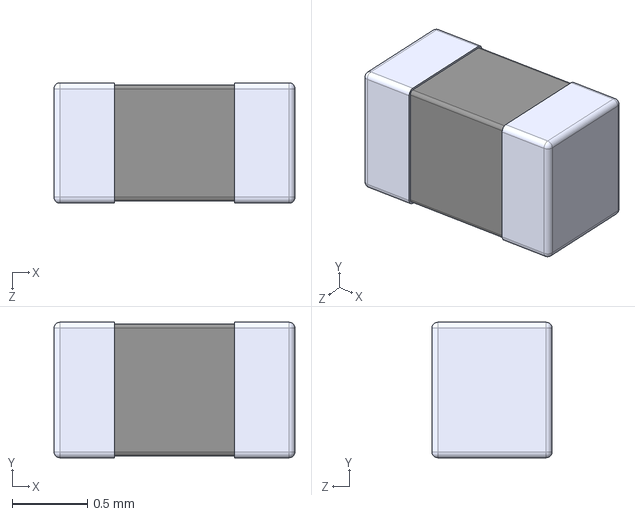
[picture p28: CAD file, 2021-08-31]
hardware/PCB/Update3-2/CC0603JRNPO9BN220/CC0603JRNPO9BN220.step
1.60 x 0.9 x 0.8 mm

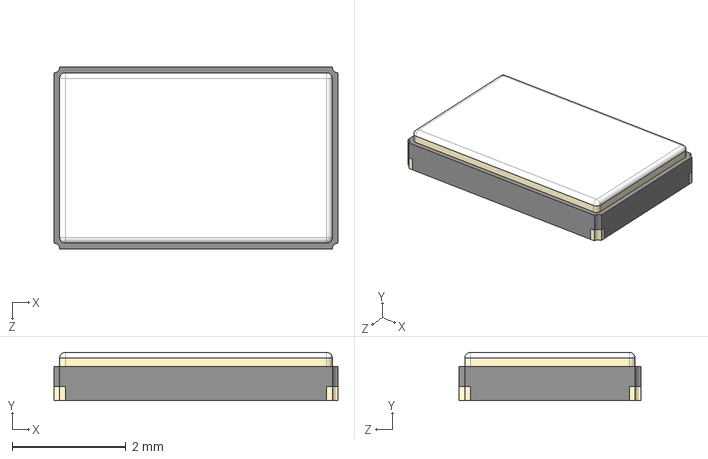
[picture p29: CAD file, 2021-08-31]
hardware/PCB/Update3-2/ECS-160-20-30B-AGL-TR/ECS-160-20-30B-AGL-TR.step
5.00 x 0.85 x 3.20 mm

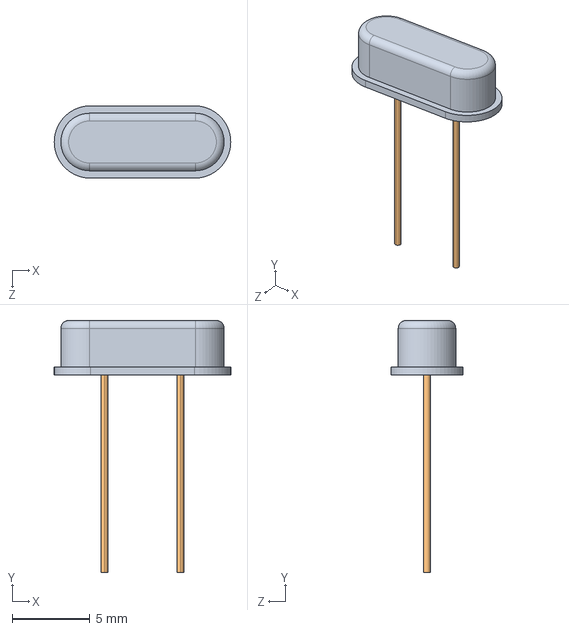
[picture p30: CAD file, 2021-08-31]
hardware/PCB/Update3-2/ECS-51-20-4/ECS-51-20-4.step
11.4 x 16.2 x 4.65 mm

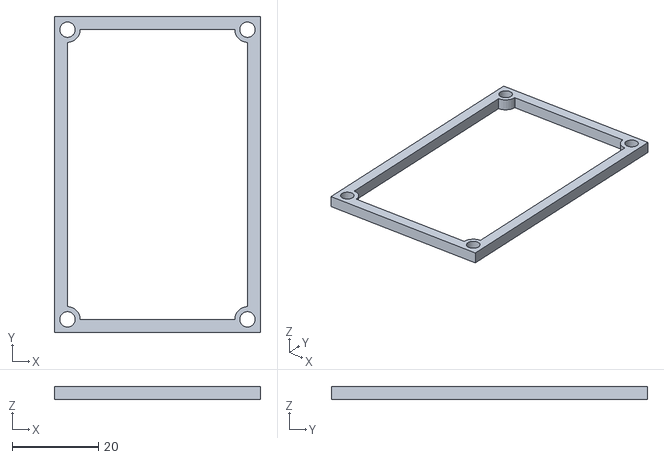
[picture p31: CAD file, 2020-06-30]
hardware/cover-plate/Plug-Pass-AC-Spacer.stl
47.8 x 73.2 x 3.00

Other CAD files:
hardware/cover-plate/Plug-Pass_Switch_Cover_v2-0.FCStd
hardware/cover-plate/Plug-Pass_AC-Spacer_v2-0.FCStd

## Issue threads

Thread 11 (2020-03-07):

Sync time by phone swipe

El1-G, 2020-03-07:
We need to add a function in the loop where if the rtc has lost power (battery failure or replacement) we are able to sync the time via a phone nfc swipe. This will also require a unique authentication key for an administrator level privilege.

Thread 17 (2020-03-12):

Susceptibility to interference on pin 12

pdockery, 2020-03-12:
I think i'm introducing some weakness in the code by reading D12 to determine if it's HIGH or LOW to decide whether to turn on or off.  it susceptible to inadvertent voltage interference on that circuit path.  Instead, i think i should write to a dummy variable whether it's high or low and track that variable with the pin write commands so it mirrors the coded output.

Closed 2020-03-16.

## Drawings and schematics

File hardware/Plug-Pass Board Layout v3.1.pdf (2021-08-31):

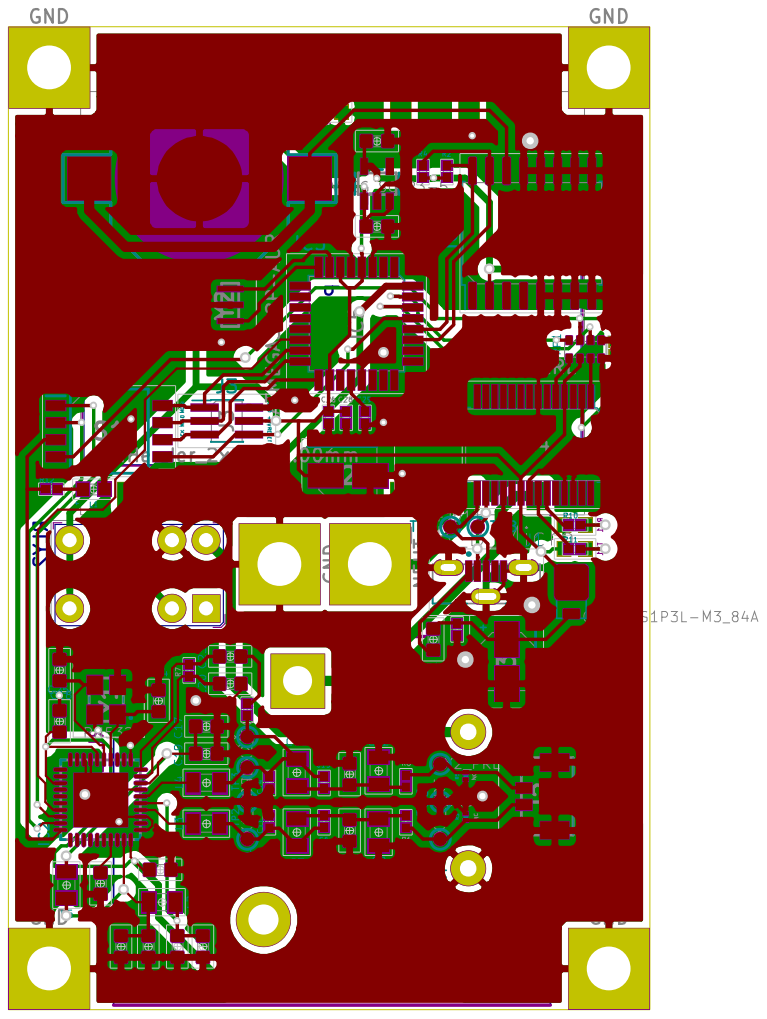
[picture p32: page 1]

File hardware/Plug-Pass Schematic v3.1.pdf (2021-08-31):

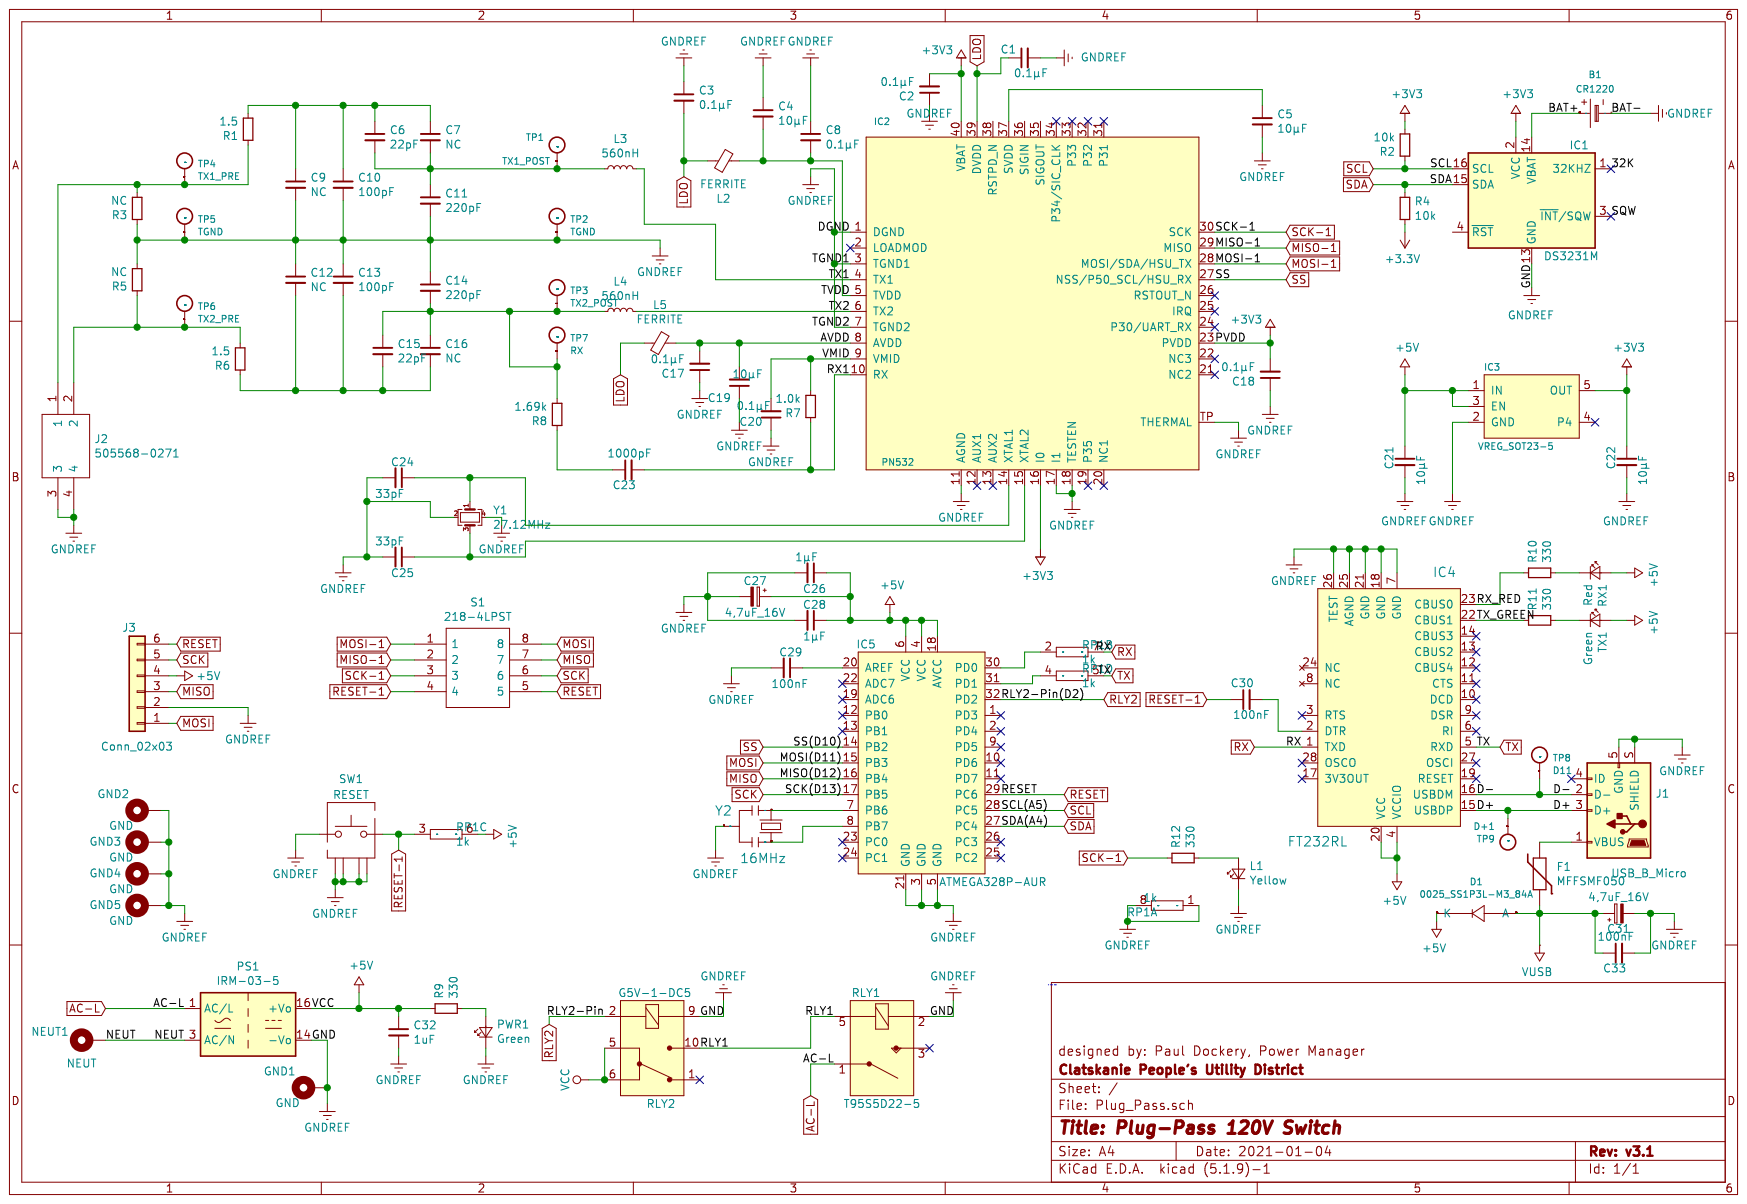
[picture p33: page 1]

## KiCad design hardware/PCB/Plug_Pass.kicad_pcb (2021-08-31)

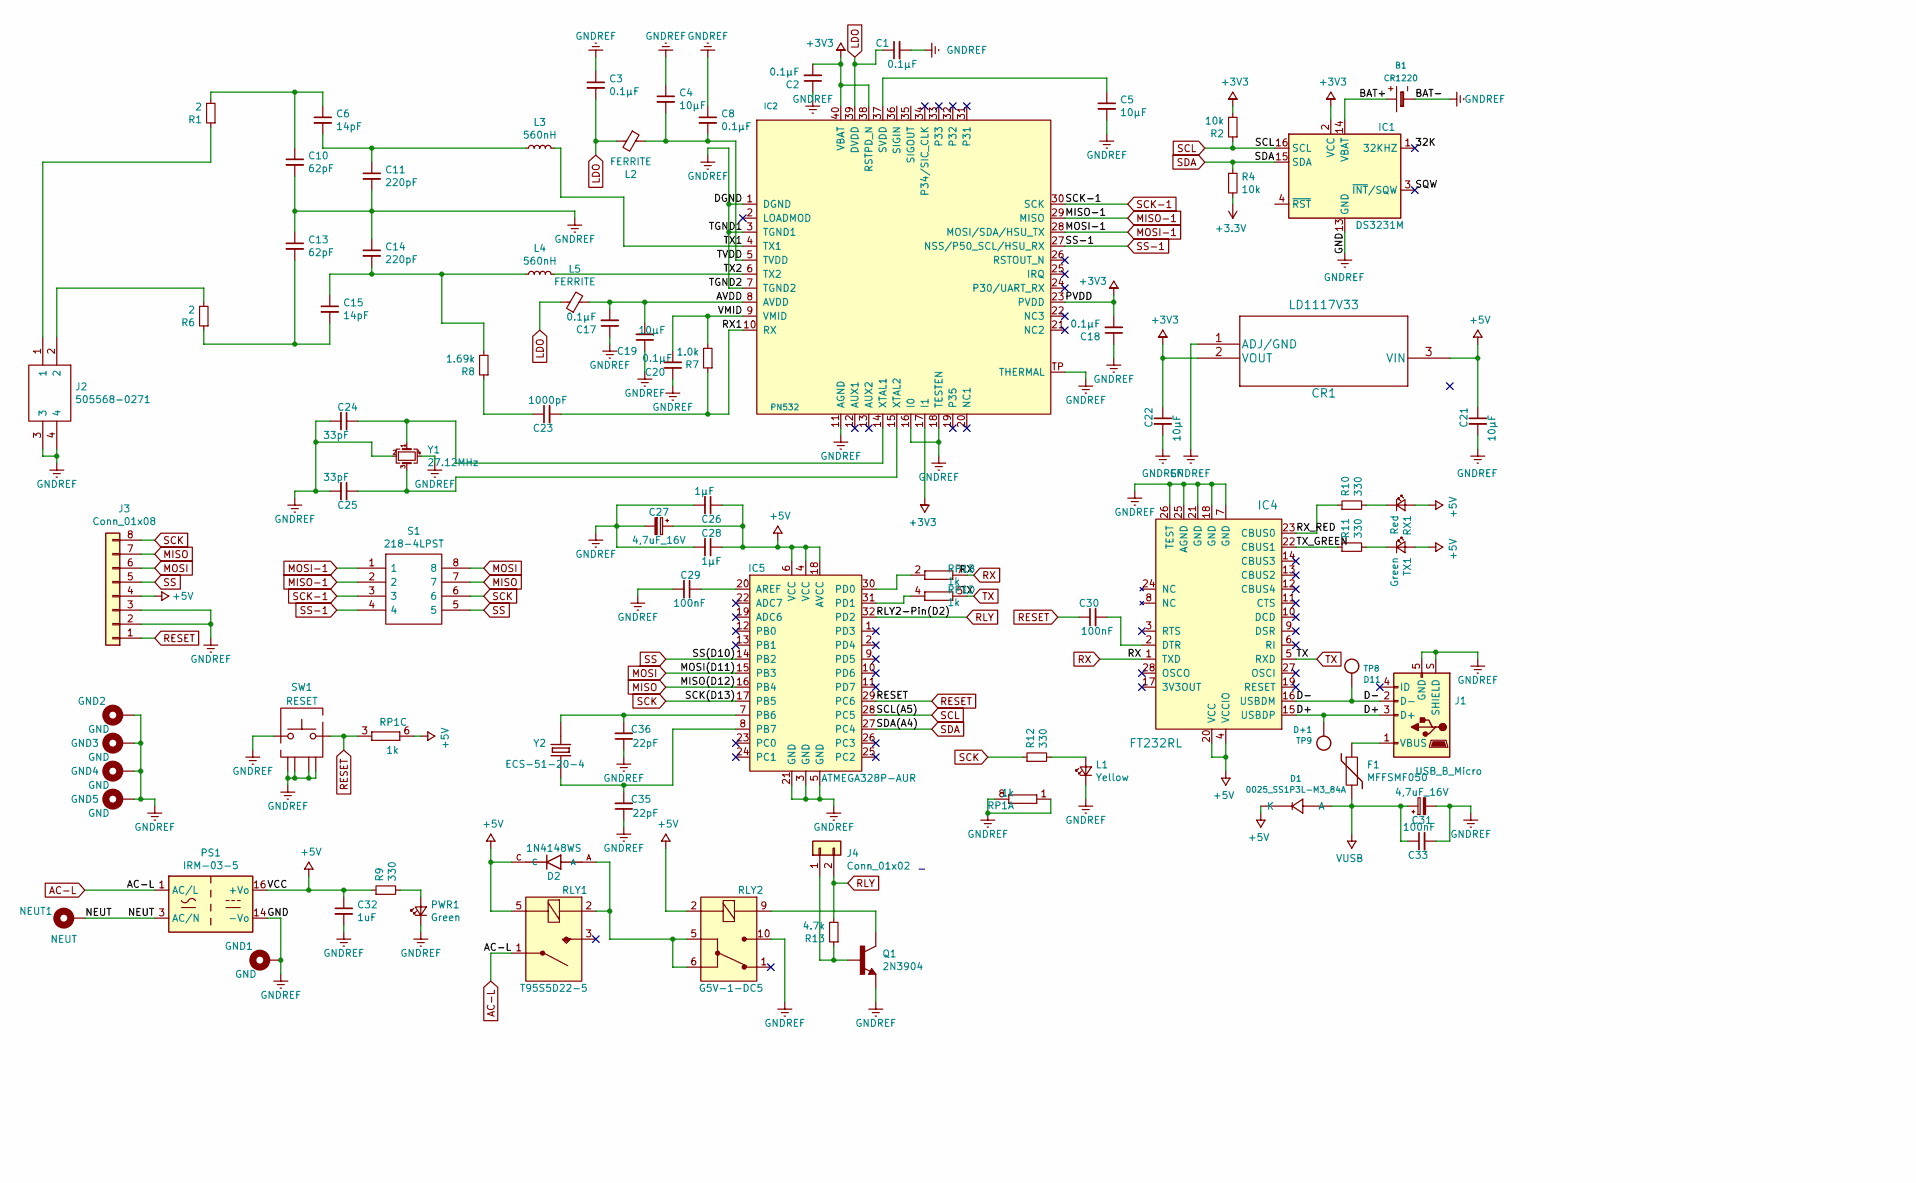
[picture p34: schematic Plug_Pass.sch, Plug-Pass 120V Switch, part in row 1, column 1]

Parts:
B1: CR1220; MPN 2894
C1, C2, C3, C8, C17, C18, C20: 0.1µF; 0603-1608X90N; MPN C0603C104K5RAC3121
C4, C5, C19, C21, C22: 10µF; 0603-1608X90N; MPN GRM188R61E106KA73D
C6, C15: 14pF; C_0805_2012Metric; MPN C1005C0G1H221J050BE
C10, C13: 62pF; C_0805_2012Metric; MPN C0603X101F5GACAUTO
C11, C14: 220pF; 0402-1005X55N; MPN C0402S221K5RACAUTO
C23: 1000pF; 0603-1608X90N; MPN C0603X102K5RAC3316
C24, C25: 33pF; 0603-1608X90N; MPN C0603C330K5HACAUTO
C26, C28: 1µF; 0402-1005X55N; MPN GRM155R61E105KA12D
C27, C31: 4,7uF_16V; CAPAE430X550N; MPN 865250340002
C29, C30, C33: 100nF; 0402-1005X55N; MPN GRM155R61H104JE14D
C32: 1uF; 0402-1005X55N; MPN GRM155R61E105KA12D
C35, C36: 22pF; 0603-1608X90N; MPN CC0603JRNPO9BN220
CR1: LD1117V33
D1: 0025_SS1P3L-M3_84A; DO220AAL; MPN SS1P3L-M3/84A
D2: 1N4148WS; SODFL2512X100N
F1: MFFSMF050; 0603-1608X90N; MPN MF-FSMF050X-2
GND1, GND2, GND3, GND4, GND5: GND; Ground_Pad
IC1: DS3231M; SOIC-16W_7.5x10.3mm_P1.27mm; MPN DS3231M+
IC2: PN532; HVQFN40-6X6; MPN PN5321A3HN/C106,55
IC4: FT232RL; SSOP-28_W5.30mm; MPN FT232RL-REEL; Digi-Key_PN 768-1007-1-ND
IC5: ATMEGA328P-AUR; TQFP-32_7x7mm; MPN ATMEGA328P-AUR; Digi-Key_PN ATMEGA328P-AURCT-ND
J1: USB_B_Micro; MOLEX_1051330001; MPN 1051330001
J2: 505568-0271; 5055680271; Mouser Part Number 538-505568-0271
J3: Conn_01x08; PinSocket_1x08_P2.54mm_Vertical_SMD_Pin1Right
J4: Conn_01x02; PinHeader_1x02_P2.54mm_Vertical
L1: Yellow; LEDC1608X80N-AK; MPN HSMY-C190
L2, L5: FERRITE; 0805-R2013X50N; MPN BLM21SP102SN1D
L3, L4: 560nH; 0805-R2013X50N; MPN CW201212-R56J
NEUT1: NEUT; Ground_Pad
PS1: IRM-03-5; Converter_ACDC_MeanWell_IRM-03-xx_SMD; MPN IRM-03-5S
PWR1: Green; LEDC1608X80N-AK; MPN HSMG-C190
Q1: 2N3904; TO92127P495H495-3; PARTREV February 2003
R1, R6: 2; R_0805_2012Metric; MPN RC0402FR-071R5L
R2, R4: 10k; 0402-1005X55N; MPN RC0402FR-0710KL
R7: 1.0k; 0402-1005X55N; MPN RC0402JR-131KL
R8: 1.69k; R_0805_2012Metric; MPN RC0402FR-071K69L
R9, R10, R11, R12: 330; 0402-1005X55N; MPN RC0402FR-07330RL
R13: 4.7k; 0402-1005X55N; MPN RC0402FR-074K7L
RLY1: T95S5D22-5; RLY-T9AS1D22-5; MPN T9AS5D22-5; Digi-Key_PN PB1015-ND
RLY2: G5V-1-DC5; Relay_THT_G5V-1; MPN G5V-1-DC5; Digi-Key_PN Z773-ND
RP1: 1k; CAY16; MPN CAY16-102J4LF
RX1: Red; LEDC1608X80N-AK; MPN HSMH-C190
S1: 218-4LPST; SOIC127P844X265-8N; Manufacturer_Part_Number 218-4LPST; Mouser Part Number 774-2184LPST
SW1: RESET; C&K_PTS820_NO_HOLES; MPN PTS820J25KSMTRLFS
TP8: D11; TESTPOINT_ROUND_1MM
TP9: D+1; TESTPOINT_ROUND_1MM
TX1: Green; LEDC1608X80N-AK; MPN HSMG-C190
Y1: 27.12MHz; 7M27120MAAJT; MPN 7M-27.120MAAJ-T
Y2: ECS-51-20-4; XTAL_ECS-51-20-4

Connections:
+5V: C21.1, C26.1, C27.1, C28.1, C32.1, CR1.3 (VIN), D1.P$1 (K), D2.C, IC4.4 (VCCIO), IC4.20 (VCC), IC5.4 (VCC), IC5.6 (VCC), IC5.18 (AVCC), J3.4, PS1.16 (+Vo), R9.1, RLY1.5 (COIL), RLY2.2 (COIL), RP1.6 (2), RX1.A, TX1.A
/32K: IC1.1 (32KHZ)
/AVDD: C17.2, C19.2, IC2.8 (AVDD), L5.2
/BAT+: B1.+$1 (+), IC1.14 (VBAT)
/D+: IC4.15 (USBDP), J1.3 (D+), TP9.P$1
/D-: IC4.16 (USBDM), J1.2 (D-), TP8.P$1
/NEUT: NEUT1.1, PS1.3 (AC/N)
/RX1: C23.2, IC2.10 (RX), R7.1
/RX_RED: IC4.23 (CBUS0), R10.1
/SQW: IC1.3 (~INT~/SQW)
/TVDD: C4.2, C8.2, IC2.5 (TVDD), L2.1
/TX1: IC2.4 (TX1), L3.2
/TX2: IC2.6 (TX2), L4.2
/TX_GREEN: IC4.22 (CBUS1), R11.1
/VMID: C20.2, IC2.9 (VMID), R7.2
AC-L: PS1.1 (AC/L), RLY1.1 (COM)
GNDREF: B1.-, C1.2, C2.1, C3.1, C4.1, C5.2, C8.1, C10.2, C11.2, C13.1, C14.1, C17.1, C18.1, C19.1, C20.1, C21.2, C22.2, C24.2, C25.2, C26.2, C27.2, C28.2, C29.2, C31.2, C32.2, C33.2, C35.1, C36.1, CR1.1 (ADJ/GND), GND1.1, GND2.1, GND3.1, GND4.1, GND5.1, IC1.5 (GND), IC1.6 (GND), IC1.7 (GND), IC1.8 (GND), IC1.9 (GND), IC1.10 (GND), IC1.11 (GND), IC1.12 (GND), IC1.13 (GND), IC2.1 (DGND), IC2.3 (TGND1), IC2.7 (TGND2), IC2.11 (AGND), IC2.16 (I0), IC2.18 (TESTEN), IC2.TP (THERMAL), IC4.7 (GND), IC4.18 (GND), IC4.21 (GND), IC4.25 (AGND), IC4.26 (TEST), IC5.3 (GND), IC5.5 (GND), IC5.21 (GND), J1.5 (GND), J1.S (SHIELD), J2.3, J2.4, J3.2, J3.3, L1.C, PS1.14 (-Vo), PWR1.C, Q1.1, RLY2.10 (NO), RP1.1, RP1.8 (2), SW1.1, SW1.3 (SH), SW1.4 (SH), SW1.5 (SH), SW1.6 (SH), Y1.2, Y1.4
LDO: C1.1, C3.2, IC2.39 (DVDD), L2.2, L5.1
MISO: IC5.16 (PB4), J3.7, S1.7
MISO-1: IC2.29 (MISO), S1.2
MOSI: IC5.15 (PB3), J3.6, S1.8
MOSI-1: IC2.28 (MOSI/SDA/HSU_TX), S1.1
unnamed: C5.1, IC2.37 (SVDD)
unnamed: C6.1, C10.1, R1.2
unnamed: C6.2, C11.1, L3.1
unnamed: C13.2, C15.2, R6.1
unnamed: C14.2, C15.1, L4.1, R8.2
unnamed: C23.1, R8.1
unnamed: C24.1, IC2.14 (XTAL1), Y1.1
unnamed: C25.1, IC2.15 (XTAL2), Y1.3
unnamed: C29.1, IC5.20 (AREF)
unnamed: C30.2, IC4.2 (DTR)
unnamed: C31.1, C33.1, D1.P$2 (A), F1.2
unnamed: C35.2, IC5.8 (PB7), Y2.1
unnamed: C36.2, IC5.7 (PB6), Y2.2
unnamed: D2.A, RLY1.2 (COIL), RLY2.5 (COM), RLY2.6 (COM)
unnamed: F1.1, J1.1 (VBUS)
unnamed: IC5.30 (PD0), RP1.2 (1)
unnamed: IC5.31 (PD1), RP1.4 (1)
unnamed: J2.1, R1.1
unnamed: J2.2, R6.2
unnamed: J4.1, Q1.2, R13.1
unnamed: L1.A, R12.2
unnamed: PWR1.A, R9.2
unnamed: Q1.3, RLY2.9 (COIL)
unnamed: R10.2, RX1.C
unnamed: R11.2, TX1.C
RESET: C30.1, IC5.29 (PC6), J3.1, RP1.3 (1), SW1.2
RLY: IC5.32 (PD2), J4.2, R13.2
RX: IC4.1 (TXD), RP1.7 (2)
SCK: IC5.17 (PB5), J3.8, R12.1, S1.6
SCK-1: IC2.30 (SCK), S1.3
SCL: IC1.16 (SCL), IC5.28 (PC5), R2.1
SDA: IC1.15 (SDA), IC5.27 (PC4), R4.1
SS: IC5.14 (PB2), J3.5, S1.5
SS-1: IC2.27 (NSS/P50_SCL/HSU_RX), S1.4
TX: IC4.5 (RXD), RP1.5 (2)

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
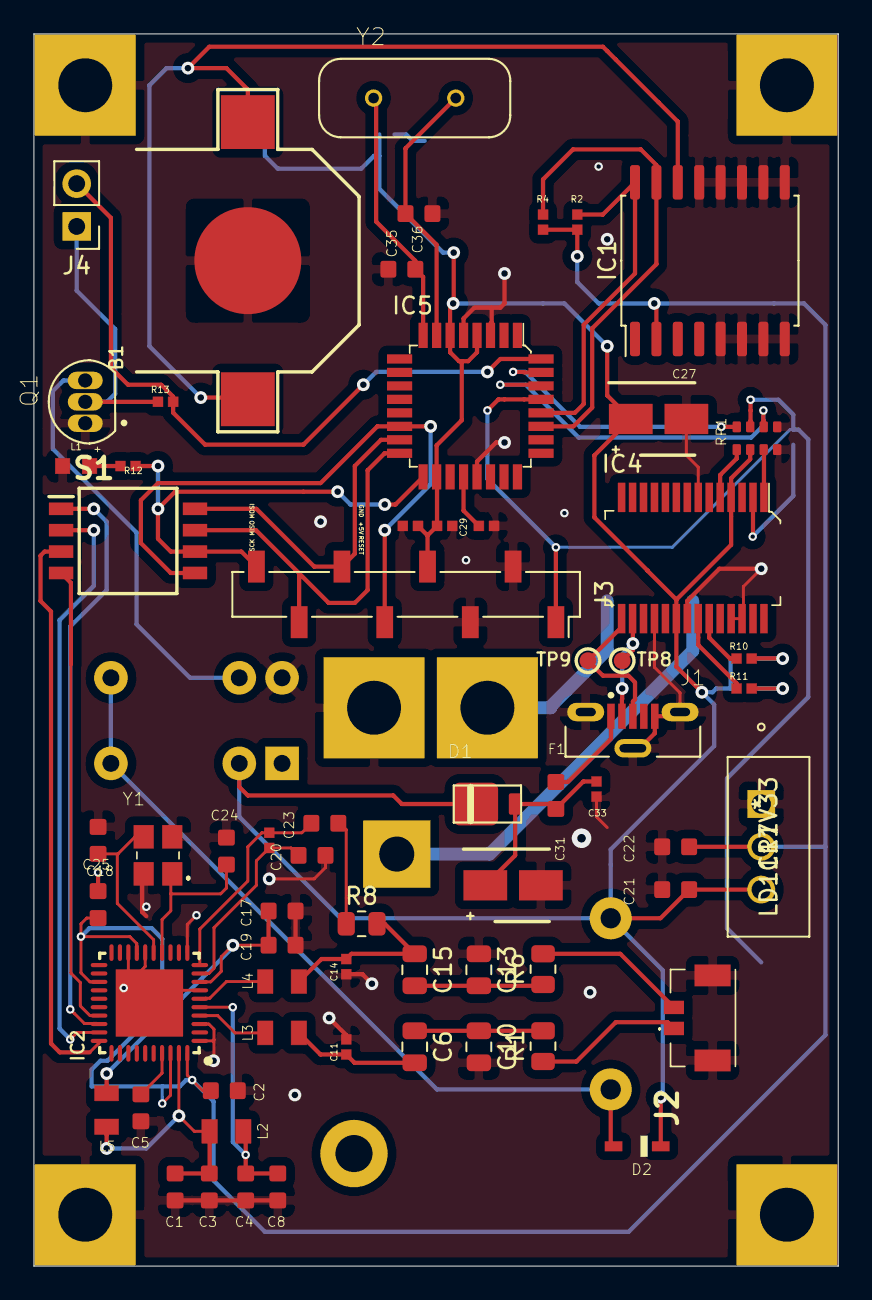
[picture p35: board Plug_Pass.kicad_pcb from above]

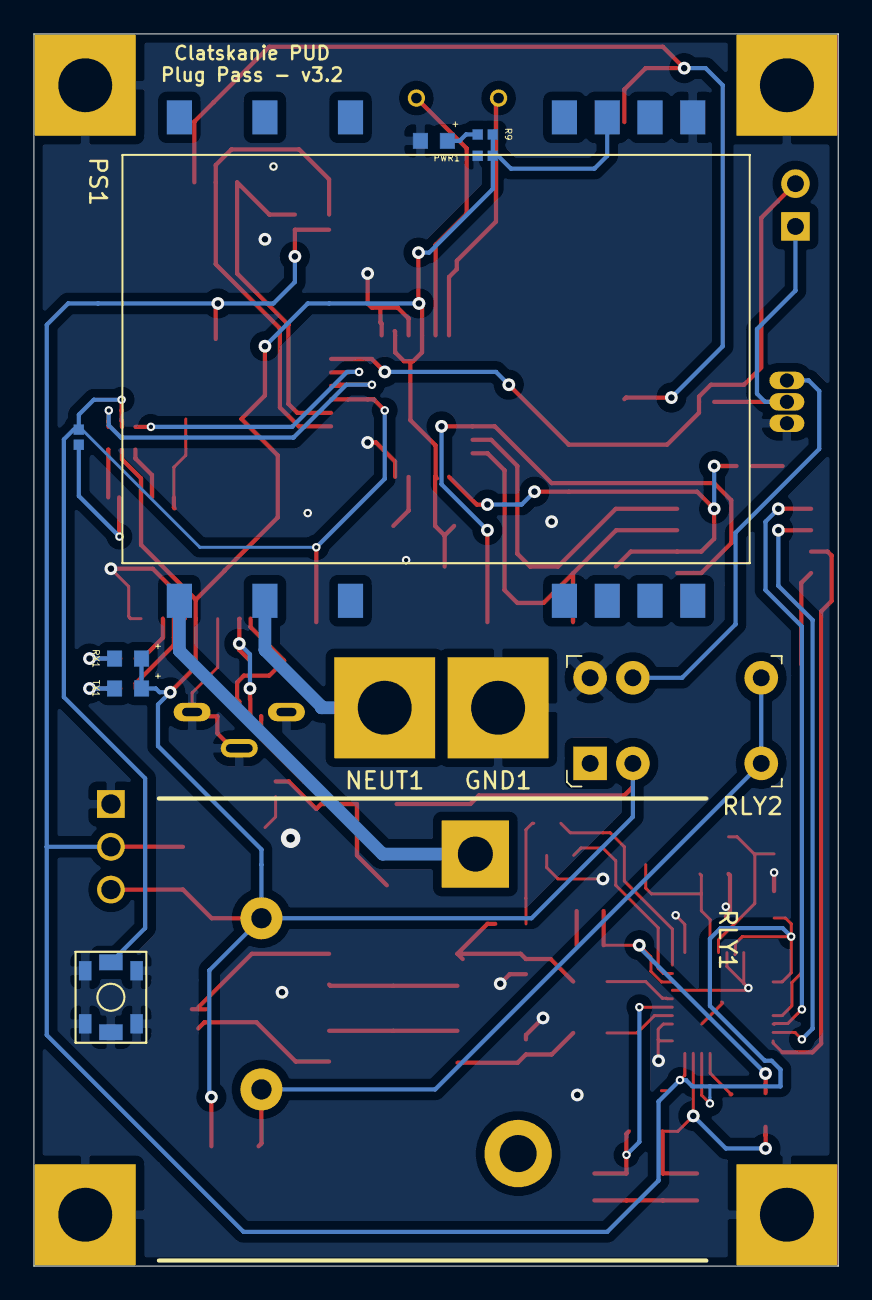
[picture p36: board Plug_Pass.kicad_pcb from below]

Board: 2 copper layers, 47.8 x 73.2 mm, 80 parts (10 on the bottom side), 56 nets.

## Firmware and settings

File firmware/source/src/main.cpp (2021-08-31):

#include <Arduino.h>
#include <Adafruit_PN532.h>
#include <EEPROM.h>
#include "Authentication_Library.h"
#include "RTClib.h"
#include "RelayManager.h"

RelayManager mRelayManager(2);
Adafruit_PN532 NFC(2, 3);
RTC_DS3231 rtc;

uint8_t success;                       // defines a variable to check the success of an NFC card scan
String cardRecord;                     // defines a variable to check the success of an NFC record scan
uint8_t uid[] = {0, 0, 0, 0, 0, 0, 0}; // Buffer to store the returned UID after NFC card scan
uint8_t uidLength;                     // Length of the UID (4 or 7 bytes depending on ISO14443A card type) for NFC card scan
uint16_t timeout = 5000;               // defines a variable to timeout the card reader function, in ms
char rx_byte = 0;                      // stores input from serial monitor
uint32_t chargeStart;                  // defines a variable to store the charge Start time
int chargeStartAddress = 0;
char daysOfTheWeek[7][12] = {"Sunday", "Monday", "Tuesday", "Wednesday", "Thursday", "Friday", "Saturday"};

void PrintDateTime(DateTime time);

void setup()
{
  Serial.begin(9600);
  delay(100);

  Serial.println(EEPROM.length());
  for (int i = 0; i <= EEPROM.length(); i++)
  {
    EEPROM.write(i, 0);
    Serial.println(i);
  }
  Serial.println("eeprom - check");
  if (!rtc.begin())
  {
    Serial.println("Couldn't find RTC");
    while (1)
      ; // I think we're going to eventually do something different, I don't want the outlet to fail if the RTC fails
  }
  Serial.println("rtc - check");
  PrintDateTime(rtc.now());

  Serial.print("LOST POWER ");
  Serial.println(rtc.lostPower());
  if (rtc.lostPower())
  {
    Serial.println("RTC lost power, lets set the time!");
    // following line sets the RTC to the date & time this sketch was compiled
    rtc.adjust(DateTime(F(__DATE__), F(__TIME__)) + 10); // This sets the RTC time to the time the sketch was compiled.  It takes 10 seconds from compiling to get to this function, so I add 10 seconds to the time
    Serial.println("RTC time set to serial time");
    PrintDateTime(rtc.now());
  }
  PrintDateTime(rtc.now());

  //SPI.begin();
  delay(1000);
  NFC.begin();
  Serial.println("nfc began");
  delay(1000);
  Serial.println("Getting data");
  uint32_t versiondata = NFC.getFirmwareVersion();
  Serial.println("Got data");
  Serial.println(versiondata);
  if (!versiondata)
  {
    Serial.print("Didn't find PN53x board");
    while (1)
      ; // I think we're going to eventually do something different, I don't want the outlet to fail if the NFC reader fails
  }
  Serial.println(versiondata);

  success = NFC.SAMConfig(); // configure board to read RFID tags
  Serial.print("SAM Config: ");
  Serial.println(success);
  Serial.println("NFC - check");
  switch (random(0, 3))
  {
  case 0:
    randomSeed(analogRead(A0));
    break;
  case 1:
    randomSeed(analogRead(A1));
    break;
  case 2:
    randomSeed(analogRead(A2));
    break;
  default:
    randomSeed(analogRead(A3));
    break;
  }
}

void loop()
{
  //mRelayManager.Test();

  rx_byte = 0;
  Serial.flush();
  Serial.println("Enter A to program Admin card, or Enter C to program Commuter card");
  while (!Serial.available())
  {
  }
  if (Serial.available() > 0)
  {                         // is a character available?
    char c = Serial.read(); // get the character
    if (c == 'A' || c == 'C')
    {
      rx_byte = c;
      Serial.println(rx_byte);
    }
  }

  if (rx_byte == 'A')
    Serial.println("programming as an Admin card");
  else if (rx_byte == 'C')
    Serial.println("programming as an Commuter card");
  else
    Serial.println("this'll be a useless card");
  delay(7000);
  Serial.println("please scan an NTAG 215 nfc card");
  success = NFC.readPassiveTargetID(PN532_MIFARE_ISO14443A, uid, &uidLength, timeout);
  Serial.println(success);
  if (success)
  {
    // Display some basic information about the card
    Serial.print("  UID Length: ");
    Serial.print(uidLength, DEC);
    Serial.println(" bytes");
    Serial.print("  UID Value: ");
    NFC.PrintHex(uid, uidLength);

    if (uidLength == 7)
    {
      uint8_t data[32];

      // We probably have an NTAG2xx card (though it could be Ultralight as well)
      Serial.println("Seems to be an NTAG2xx tag (7 byte UID)");

      // NTAG2x3 cards have 39*4 bytes of user pages (156 user bytes),
      // starting at page 4 ... larger cards just add pages to the end of
      // this range:

      // See: http://www.nxp.com/documents/short_data_sheet/NTAG203_SDS.pdf

      // TAG Type       PAGES   USER START    USER STOP
      // --------       -----   ----------    ---------
      // NTAG 203       42      4             39
      // NTAG 213       45      4             39
      // NTAG 215       135     4             129
      // NTAG 216       231     4             225

      Serial.println("");
      Serial.println("Writing randomly generated codes to pages 4..129");
      Serial.println("");
      for (uint8_t i = 4; i <= 129; i++)
      {
        // String randomKey = keyDB.GeneratePsuedoRandomKey();
        // //SetCardRecord(i, randomKey);
        // delay(10);
        // //PrintCardRecord(i);
      }

      if (rx_byte == 'A')
      {
        // Serial.println("setting Admin code");
        // String key = keyDB.validAdminKeys[0];
        // SetCardRecord(keyDB.initializationPageOne, key.substring(0, 4));
        // delay(10);
        // PrintCardRecord(keyDB.initializationPageOne);
        // SetCardRecord(keyDB.initializationPageTwo, key.substring(4, 8));
        // delay(10);
        // PrintCardRecord(keyDB.initializationPageTwo);
      }
      if (rx_byte == 'C')
      {
        // Serial.println("setting Commuter code");
        // String key = keyDB.validOneTimeKeys[0];
        // SetCardRecord(keyDB.initializationPageOne, key.substring(0, 4));
        // delay(10);
        // PrintCardRecord(keyDB.initializationPageOne);
        // SetCardRecord(keyDB.initializationPageTwo, key.substring(4, 8));
        // delay(10);
        // PrintCardRecord(keyDB.initializationPageTwo);
      }
    }
    else
    {
      Serial.println("This doesn't seem to be an NTAG203 tag (UUID length != 7 bytes)!");
    }

    // Wait a bit before trying again
    Serial.println("save successful");

    PrintDateTime(rtc.now());
  }
}

void PrintDateTime(DateTime time)
{
  Serial.print(time.year(), DEC);
  Serial.print('/');
  Serial.print(time.month(), DEC);
  Serial.print('/');
  Serial.print(time.day(), DEC);
  Serial.print(" (");
  Serial.print(daysOfTheWeek[time.dayOfTheWeek()]);
  Serial.print(") ");
  Serial.print(time.hour(), DEC);
  Serial.print(':');
  Serial.print(time.minute(), DEC);
  Serial.print(':');
  Serial.print(time.second(), DEC);
  Serial.println();
}

void SetCardRecord(uint8_t page, String key)
{
  uint8_t buf[6];
  memset(buf, 0, sizeof(buf));

  //key.toCharArray(buf,5);

  success = NFC.ntag2xx_WritePage(page, buf);
  byte i = 1;
  while (!success && i <= 10)
  {
    Serial.println("Unable to write to the requested page! retrying");
    delay(100);
    success = NFC.readPassiveTargetID(PN532_MIFARE_ISO14443A, uid, &uidLength);
    if (success)
    {
      success = NFC.ntag2xx_WritePage(page, buf);
    }
    i = i + 1;
  }
}

void PrintCardRecord(uint8_t page)
{
  uint8_t data[32];

  success = NFC.ntag2xx_ReadPage(page, data);
  Serial.print("Page ");
  Serial.print(page);
  Serial.print(": ");

  if (success)
  {
    // Dump the page data
    NFC.PrintHexChar(data, 4);
  }

  byte i = 1;
  while (!success && i <= 10)
  {
    Serial.println("Unable to read the requested page! retrying");
    delay(100);
    success = NFC.readPassiveTargetID(PN532_MIFARE_ISO14443A, uid, &uidLength);
    if (success)
    {
      success = NFC.ntag2xx_ReadPage(page, data);
      NFC.PrintHexChar(data, 4);
    }
    i = i + 1;
  }
}

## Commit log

2020-02-26 Create Arduino_Sketch_file
2020-02-26 Add arduino sketch
2020-03-04 commented out while loop
    there was a while look that kept looping and locked up the code. commented out. also added some time prints to check if it went through the loop.
2020-03-05 Update to print legible dates to serial monitor
    Updated date formats so it prints something legible to the serial monitor. (mostly a learning experiment)
2020-03-06 Now enables relay on digital pin 12
    Also moved the date printing to a single function to clean the code up a bit. For testing purposes the relay is triggered for 3 seconds on startup if there is still time remaining on the last charge 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
2020-03-09 First stage - this is not done
    not done, but cleaned alittle. have been working on the time issue. i think it's either a bad module or a bad battery.
2020-03-12 Update - variable data types
    Updated variable data types for the timeout in the card reader, and the charge time.
2020-03-12 data type data type data type
    i keep messing up data types. aligned data types for the charge_time and chargeStart variables so they calculate faster.
2020-03-16 Update - defines a chargeStatus variable
    created a chargeStatus variable to hold the most recent command of off or on that i can reference instead of reading the pin status.
2020-04-02 Upload Example EV Public Charging Rate Schedule
2020-04-07 create PCB subfolder in hardware
2020-04-07 add KiCAD files
    [Plug_Pass.sch]
2020-04-08 Upload KiCAD files
    [Plug_Pass.kicad_pcb, Plug_Pass.sch]
2020-04-08 create gitignore file in pcb directory
2020-04-10 add current files through upload
    includes revised schematic and updated library with parts
    [Plug_Pass.sch]
2020-04-13 Update plug_pass_control_protocol.ino
    reconfigured the SPI wiring so that the wires didn't have to cross. thought it might make wiring and pcb printing a little easier.
    [plug_pass_control_protocol.ino]
2020-04-13 Schematic update for SPI wiring of NFC reader
    Corresponding update to the PCB schematic to correspond to the firmware update.
    [Plug_Pass.kicad_pcb, Plug_Pass.sch]
2020-04-15 Uploaded revised schematic and pcb layout
    Uploaded revisions to the KiCAD schematic, and included phase 1 of the PCB layout design process.
    [Plug_Pass.sch]
2020-04-16 Version 1 of a full PCB design
    This push has a full KiCAD package for a set of boards. Still in draft, but it's complete.
    [Plug_Pass.kicad_pcb, Plug_Pass.sch]
2020-04-16 Added footprints folder
2020-04-21 Revised KiCAD project
    added a 120V schematic and pcb board layout that reduces the footprint so it fits in a normal 120V switch slot.
    [Plug_Pass.kicad_pcb, Plug_Pass_120V.kicad_pcb, Plug_Pass_120V.sch]
2020-04-21 upload most recent KiCAD files
    Revised KiCAD footprint files in most recent iteration.
2020-04-22 KiCAD files from first prototype batch
    [Plug_Pass_120V_AC_shield.kicad_pcb, Plug_Pass_120V_arduino_shield.kicad_pcb]
2020-04-22 KiCAD gerber files from first prototype board
    [Plug_Pass_120V_AC_shield-B_Cu.gbl, Plug_Pass_120V_AC_shield-B_Mask.gbs, Plug_Pass_120V_AC_shield-B_SilkS.gbo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]
2020-05-14 Add initialization file
    sets up both the arduino and the rfid cards
2020-05-28 add revised pcb parts list
    [DigiKey Plug-Pass PCB Parts List v1-2 -2020-05-28T152531.xlsx]
2020-06-30 Version 2.0 of the 3D printed enclosure
    [Plug-Pass-AC-Spacer.stl, Plug-Pass-cover.stl, Plug-Pass_AC-Spacer_v2-0.FCStd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]
2020-08-24 Update plug_pass_control_protocol.ino
    found a better way to set the charge ending time
2020-12-08 Create BOM
2021-05-20 Added platformio project, moved arduino sketches to their own folder
2021-05-20 Changed build to correct board
2021-05-20 Added relay class
2021-05-21 Code used to validate board modules
2021-06-09 Board update v3.2
    [1N4148WS.step, 2N3904.step, AntennaDesign.xls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]

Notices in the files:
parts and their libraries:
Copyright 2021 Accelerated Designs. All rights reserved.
